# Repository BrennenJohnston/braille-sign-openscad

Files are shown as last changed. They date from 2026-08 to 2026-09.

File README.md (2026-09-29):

# Braille Sign STL Generator (OpenSCAD)





## Overview

A parametric OpenSCAD generator for **two-part tactile signs**: a plate of
raised uppercase letters above a plate of the same wording in braille, following
the 2010 ADA Standards (section 703) recommendations. It is for anyone who needs
a room sign that reads by touch as well as by sight, and for the makers who
print them. The letter plate prints flat and the braille plate prints leaning
back at 75 degrees on break-away fins, because braille printed at 75 to 90
degrees reads faster and more comfortably than flat-printed braille; mounted
touching, the two plates' split borders join into one frame.

One self-contained `.scad` file, MakerWorld-ready, no `include`/`use`.

The picture below shows the default sign the way the printer makes it: the
letter plate lies flat with ROOM 101 in raised letters inside a raised border,
and the braille plate leans back on a row of thin support fins that snap off
after printing. This view shows the back of the braille plate, so its dots face
away from you.

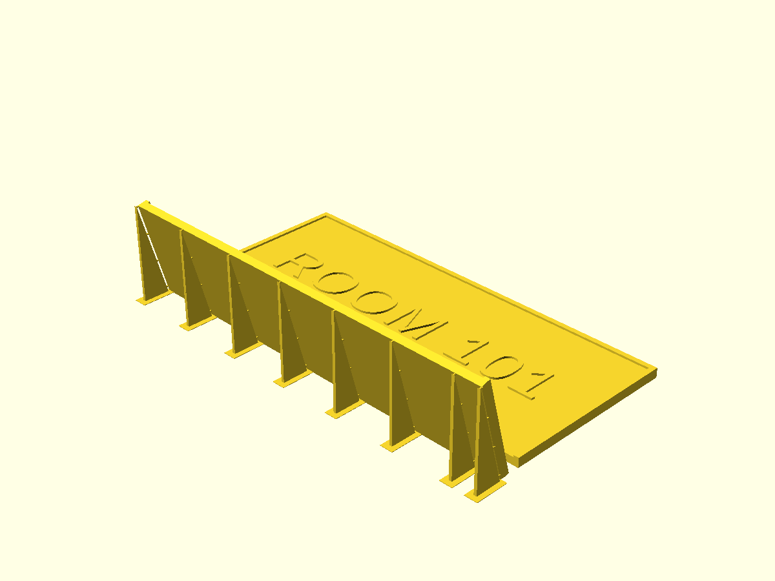
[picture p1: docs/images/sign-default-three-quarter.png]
The default sign as it prints, seen from above and in front. The letter plate lies flat with ROOM 101 in raised capital letters inside a raised border. In front of it the braille plate leans back on a row of thin support fins; this view shows its back and fins, and its braille dots face away.


The two guides to read first: the [quick start](docs/guides/quick-start.md)
(one page, from your wording to a sign on the wall) and the
[Maker Guide](docs/guides/maker-guide.md) (the same path in more depth).

> **ADA note.** The defaults follow the published §703 figures, but this tool
> does **not** guarantee compliance. Real signage has requirements this
> generator does not model — mounting height and location, contrast, glare,
> character width ratios, and the 9.5 mm (3/8 in) minimum braille offset below
> the raised text. Verify against the standard before installing.

## How to obtain the device

### In your browser with the Forge

<https://openscad-assistive-forge.pages.dev/?example=braille-sign>

The Forge is an accessibility-first web customizer that runs entirely in your
browser — no account, no uploads, no OpenSCAD install. It ships this generator
as a built-in tool and translates plain text to Grade 1 or Grade 2 Unicode
braille on your device via liblouis, so you can skip the manual translation
step. It updates its own copy of the generator separately, so its dial names
and defaults can differ from this repository's.

### On your computer with OpenSCAD

Open `Braille_Sign_STL_Generator.scad` in [OpenSCAD](https://openscad.org/)
2021.01 or newer (a development snapshot renders fastest) and show the
Customizer (Window > Customizer; in 2021.01, untick Window > Hide Customizer).
Fill in the four Steps from the top: in **Step 1 - Pick a sample sign or type
your own**, pick a `sample_sign` or type your wording into `text_line_1` to
`text_line_6`; in **Step 2 - Braille, pasted from a translator**, paste Unicode
braille into `braille_line_1` to `braille_line_6`; in **Step 3 - What to
export**, choose `sign_part` and leave `print_orientation` on `Angled`; in
**Step 4 - Size**, leave `auto_fit` on `Yes`. Press F6 to render and export each
plate as an STL. The [quick start](docs/guides/quick-start.md) has every click,
and red words beside the sign in the preview name a problem that the full
guide's [Warnings and notes](docs/guides/full-guide.md#warnings-and-notes)
explains.

`Braille_Sign_STL_Generator.json` sits next to the `.scad`, so OpenSCAD
auto-loads its parameter sets into the Customizer preset dropdown:

- **Default Sign (both plates)** — the first-run defaults.
- **Braille Plate Only (flat)** — one plate, printed dots-up.

Your own saved parameter sets go in the same dropdown via the Customizer's `+`
button. If you keep personal presets (names, contact info in braille), save them
to a file ending in `.local.json` — that pattern is gitignored so they never end
up in a public commit.

### A ready-to-print sample

No OpenSCAD needed: the [`stl/`](stl) folder holds both plates of the Restroom,
Exit, Stairs and Room 101 signs, ready to print. [`stl/README.md`](stl/README.md)
lists each file with its size and print settings.

### MakerWorld

The listing is prepared in
[`docs/MAKERWORLD_LISTING.md`](docs/MAKERWORLD_LISTING.md) and goes live when
the owner publishes it. MakerWorld's Parametric Model Maker takes only the
`.scad` (the `.json` presets do not upload), and it shows no OpenSCAD console,
so [`docs/MAKERWORLD_QUICK_START.md`](docs/MAKERWORLD_QUICK_START.md) describes
each problem by what you can see instead. Both are written to the shared
[Accessible MakerWorld Documentation Standard](https://github.com/BrennenJohnston/accessible-makerworld-doc-standard/blob/main/ACCESSIBLE_MAKERWORLD_DOC_STANDARD.md).

## Build instructions

The [Maker Guide](docs/guides/maker-guide.md), section by section:

1. [Choose a way](docs/guides/maker-guide.md#1-choose-a-way)
2. [Prepare the wording](docs/guides/maker-guide.md#2-prepare-the-wording)
3. [Customize](docs/guides/maker-guide.md#3-customize)
4. [Print](docs/guides/maker-guide.md#4-print)
5. [Mount](docs/guides/maker-guide.md#5-mount)
6. [Check it](docs/guides/maker-guide.md#6-check-it)

What to buy besides filament is in the [bill of materials](docs/guides/bom.md).

## How to use it

The [User Guide](docs/guides/user-guide.md) is for the people who put the sign
up, read it and look after it: who it is for, where ADA 703.4 puts it, how it
reads, care, and its limits.

## How to improve this device

The [full guide](docs/guides/full-guide.md) explains how the sign is built,
every dial, every warning and note, the renamed dials, and the command line.
The [design rationale](docs/guides/design-rationale.md) gives the reason and the
measured number behind each default.

```bash
pip install -r tests/requirements.txt
pytest tests -v
```

- `tests/test_customizer.py`: the dropdowns are well formed, and the presets
  file names only real dials and holds no personal text.
- `tests/test_source_guards.py`: one self-contained file, the pinned font, the
  three export choices, six text and braille line pairs, the tab layout,
  dropdown labels without parentheses, and the braille sliders inside ADA
  Table 703.3.1.
- `tests/test_sample_signs.py`: the sample data is well formed and matches the
  dropdown and the file's tables.
- `tests/test_ada_figures.py`: the capital I height, the width estimate within
  2 %, the braille's 9.5 mm clearance, and the character table against its
  data file.
- `tests/test_render_smoke.py`: each plate renders as one solid, and the
  preview warnings never reach an export.
- `tests/test_release_stls.py`: `stl/README.md` lists every shipped STL, and
  the shipped Restroom letter plate still matches a fresh render.
- `tests/test_full_guide_covers_every_dial.py`: the full guide names every
  dial, quotes every warning and note, and matches the sample data.
- `tests/test_docs_gate.py`: this README and every page under `docs/` meet the
  documentation rules that `scripts/check_docs.py` checks.

The tests marked `requires_openscad` render the sign and need OpenSCAD
installed. `powershell -ExecutionPolicy Bypass -File scripts\scad-check.ps1`
renders the default sign with strict warnings and prints `CHECK PASSED` or
`CHECK FAILED`; [`scripts/README.md`](scripts/README.md) lists every script.
CI (GitHub Actions) runs a lint check, every test that needs no OpenSCAD, and
the render smoke tests on Ubuntu with an OpenSCAD nightly AppImage, on every
pull request.

### Related projects

- [braille-wedge-card-openscad](https://github.com/BrennenJohnston/braille-wedge-card-openscad)
  — directly readable braille cards on the same 75° leaning technique. **This
  generator's commit history lives there**, where it shipped as part of v1.1.0
  before moving to this repo.
- [braille-charm-openscad](https://github.com/BrennenJohnston/braille-charm-openscad)
  — braille charms, pendants, and bracelet clips; split out of the same repo.
- [OpenSCAD Assistive Forge](https://github.com/BrennenJohnston/openscad-assistive-forge)
  — accessibility-first browser customizer that ships all three as built-in
  tools with automatic braille translation
  ([live demo](https://openscad-assistive-forge.pages.dev/)).
- [braille-cylinder-stl-generator-openscad](https://github.com/BrennenJohnston/braille-cylinder-stl-generator-openscad)
  — braille **embossing plates** (emboss + counter pairs) for cylindrical
  objects. The dot geometry here traces back to it.

## Files

Documentation:

| File | What it is |
|---|---|
| `README.md` | this page |
| `docs/guides/quick-start.md` | the whole path on one page |
| `docs/guides/maker-guide.md` | how to make the sign |
| `docs/guides/user-guide.md` | how to place, read and look after it |
| `docs/guides/full-guide.md` | every dial, warning and note |
| `docs/guides/bom.md` | what to buy, and filament per sample |
| `docs/guides/design-rationale.md` | why each default is what it is |
| `docs/MAKERWORLD_LISTING.md` | the MakerWorld listing, ready to paste |
| `docs/MAKERWORLD_QUICK_START.md` | using the file on MakerWorld |
| `CHANGELOG.md` | what changed in each version |
| `okh.yml` | the Open Know-How manifest |

Design files:

| File | What it is |
|---|---|
| `Braille_Sign_STL_Generator.scad` | the generator: open it in OpenSCAD and use the Customizer |
| `Braille_Sign_STL_Generator.json` | Customizer presets, auto-loaded by OpenSCAD |
| `scripts/sample_signs.json` | the sample signs' wording and braille, from liblouis |
| `scripts/glyph_advances.json` | the letter widths behind the width estimate |

Build files:

| File | What it is |
|---|---|
| `stl/*.stl` | both plates of each sample sign, ready to print |
| `stl/README.md` | each STL with its size and print settings |
| `docs/images/*.png` | the preview pictures the guides show |

## License

**PolyForm Noncommercial 1.0.0** — free for personal, educational, and other
noncommercial use; modification and redistribution allowed under the same
terms; **no commercial use**. See [LICENSE](LICENSE). MakerWorld, Printables
and Thingiverse do not offer PolyForm, so the copies there carry the closest
license they do offer, Creative Commons Attribution-NonCommercial 4.0
(CC BY-NC 4.0), chosen by the owner.

## Attribution

- **Brennen Johnston** — project owner; braille dot system and the leaning /
  break-away fin geometry.
- **Puerta, Crnovrsanin, South, Dunne (CHI 2024)** — the orientation research
  the angled braille plate is built on.
- **masukomi** and **Slant3D** — break-away support fin technique.

The research behind the defaults:

- [Puerta et al., CHI 2024](https://doi.org/10.1145/3613904.3642719), "The
  Effect of Orientation on the Readability and Comfort of 3D-Printed Braille":
  braille printed at 75–90° reads significantly faster and more comfortably than
  flat; 75° also reduces dot overhangs vs. 90°. The angled braille plate exists
  for this reason.
- [masukomi, "Manual Support Fins for 3D Printing"](https://weblog.masukomi.org/2024/03/11/manual-support-fins-for-3d-printing/):
  ~1 mm fin offset, a column of small sprues, side fins so edges don't float,
  0.3–0.4 mm contact — the fin/bridge defaults follow this.
- [2010 ADA Standards](https://archive.ada.gov/), section 703: character
  height, raise height, and dot dimension envelope behind the defaults.
- [BANA size and spacing](https://brailleauthority.org/size-and-spacing-braille-characters):
  cell geometry and clear-space guidance behind the spacing defaults.

The documentation and repository structure follow the OpenAT Template created by
Makers Making Change / Neil Squire Society, used under a CC BY-SA 4.0 license:
[github.com/makersmakingchange/OpenAT-Template](https://github.com/makersmakingchange/OpenAT-Template).

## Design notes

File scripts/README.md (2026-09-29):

# Scripts

Helper scripts for this repository. Run each one from the repository root.

| Script | What it does | How to run it |
|---|---|---|
| `scad-check.ps1` | Renders the generator with strict warnings and OpenSCAD's own parameter checks into `build/check.stl`, then prints `CHECK PASSED` or `CHECK FAILED`. | `powershell -ExecutionPolicy Bypass -File scripts\scad-check.ps1` |
| `generate_sample_braille.mjs` | Translates the sample signs to UEB Grade 2 braille with liblouis and writes `scripts/sample_signs.json`. | `node scripts/generate_sample_braille.mjs` |
| `measure_glyph_advances.py` | Measures each character's width in Liberation Sans with OpenSCAD and writes `scripts/glyph_advances.json` and the `GLYPH_METRICS` table. | `python scripts/measure_glyph_advances.py` |
| `build_release_stls.py` | Renders both plates of every sample sign into `stl/`, checks each is watertight, and writes `stl/README.md`. | `python scripts/build_release_stls.py` |
| `render_doc_images.py` | Renders the preview pictures the guides show into `docs/images/` and prints each file's size. | `python scripts/render_doc_images.py` |
| `check_docs.py` | Checks `README.md` and every page under `docs/` against the documentation rules and prints each finding; exits 1 if any fails. | `python scripts/check_docs.py` |

`measure_glyph_advances.py` is run by hand when the font or the width estimate changes; paste the table it prints into the `.scad`.

`build_release_stls.py` is run by hand after any change to the `.scad` that moves the geometry, and the regenerated files are committed; `--out <folder>` renders somewhere else to compare without touching `stl/`.

`render_doc_images.py` is run by hand after a change to the `.scad` that changes what the pictures show; `--only <name>` renders one picture. Look at each picture, and check its alt text in the guide still matches, before committing it.

`check_docs.py` runs in CI through `tests/test_docs_gate.py`; run it yourself after editing the README or any page under `docs/`. Findings in a file a later phase will rewrite print with that phase's tag and do not fail it.

`generate_sample_braille.mjs` is run by hand, never in CI. It needs a local clone of the OpenSCAD Assistive Forge with its liblouis package and braille tables installed; the path is set at the top of the script. Braille in this repository always comes from this script, never typed by hand, and `tests/test_sample_signs.py` checks the file it writes.

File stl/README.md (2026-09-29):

# Sample sign STLs

Ready-to-print plates for the built-in sample signs, rendered from `Braille_Sign_STL_Generator.scad` at its defaults by `scripts/build_release_stls.py`. Each sign is two plates: print both and mount the letter plate above the braille plate.

- Letter plate: print it flat, letters up, at 0.2 mm layers.
- Braille plate: print it as modeled, leaning back on its fins, at 0.1 mm layers with no slicer supports, then snap the fins off.

| File | Sample | Plate | Size (mm) | Print with |
|---|---|---|---|---|
| `restroom-letter-plate.stl` | Restroom | Letter plate | 160.0 × 70.0 × 3.8 | 0.2 mm layers, flat, letters up |
| `restroom-braille-plate.stl` | Restroom | Braille plate | 165.2 × 17.0 × 39.0 | 0.1 mm layers, as modeled, no supports |
| `exit-letter-plate.stl` | Exit | Letter plate | 160.0 × 70.0 × 3.8 | 0.2 mm layers, flat, letters up |
| `exit-braille-plate.stl` | Exit | Braille plate | 165.2 × 17.0 × 39.0 | 0.1 mm layers, as modeled, no supports |
| `stairs-letter-plate.stl` | Stairs | Letter plate | 160.0 × 70.0 × 3.8 | 0.2 mm layers, flat, letters up |
| `stairs-braille-plate.stl` | Stairs | Braille plate | 165.2 × 17.0 × 39.0 | 0.1 mm layers, as modeled, no supports |
| `room-101-letter-plate.stl` | Room 101 | Letter plate | 160.0 × 70.0 × 3.8 | 0.2 mm layers, flat, letters up |
| `room-101-braille-plate.stl` | Room 101 | Braille plate | 165.2 × 17.0 × 39.0 | 0.1 mm layers, as modeled, no supports |

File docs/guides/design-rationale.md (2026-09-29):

# Design rationale

Every default in the generator has a reason. This page gives each one in the
same shape: the decision, the number, the evidence, and what you may change.
The numbers were measured on the files in this repository, and each one names
where it came from.

> **ADA note.** The defaults follow the published §703 figures, but this tool
> does **not** guarantee compliance. Real signage has requirements this
> generator does not model — mounting height and location, contrast, glare,
> character width ratios, and the 9.5 mm (3/8 in) minimum braille offset below
> the raised text. Verify against the standard before installing.

## Two plates, and the braille plate leans back 75°

**The decision.** The sign is two plates. The letter plate prints flat,
letters up. The braille plate prints leaning back on break-away fins:
`print_orientation` is `Angled` and `face_angle_deg` is 75.

**The number.** 75 degrees from the bed. The leaning plate is sunk 0.6 mm into
the bed and cut flat there, so its bottom edge has a real first-layer strip
instead of a knife edge. A fin stands at each end and every 25 mm between
(`fin_interval_mm`): eight fins on the default 160 mm sign. All of these are
in `Braille_Sign_STL_Generator.scad`.

**The evidence.** The Accessible MakerWorld Documentation Standard, section 2,
copied here as it stands:

> **Puerta, Crnovrsanin, South, Dunne — "The Effect of Orientation on the
> Readability and Comfort of 3D-Printed Braille," CHI 2024.** DOI
> [10.1145/3613904.3642719](https://doi.org/10.1145/3613904.3642719)
>
> Why it matters: braille printed on a face angled **75°–90°** from the print
> bed was read significantly faster and more comfortably than flat-printed
> braille, because near-vertical printing moves the layer seams off the surface
> the finger reads. **75°** rather than 90° is the working choice here because it
> reduces the overhang under each dot.

That finding is about braille dots, not raised letters. A dot is 1.6 mm
across, so a layer seam over its crown is a large part of it, and a finger
feels it. A raised letter 16 mm tall is coarse enough that seams do not
matter, and printing it flat gives a cleaner top than any angle would. One
plate would force both kinds of text into one orientation, so the sign is two
plates. At 90 degrees the underside of every dot would be a flat overhang; at
75 degrees the face tilts back and each dot's underside becomes a gentle slope
that prints without supports. The fins, bridges and brims exist to make that
angle printable in one pass.

**What you may change.** `face_angle_deg` runs from 60 to 90; 75 to 90 reads
best, and 75 needs no slicer supports. `print_orientation` `Flat` prints the
braille plate dots up, which puts the layer seams across the dots. The fin,
bridge and brim dials change how the fins hold and how easily they snap off.

## The letter dimensions

**The decision.** `letter_height_mm` is the printed height of the capital I,
16 mm by default. The letters rise 0.8 mm (`letter_raise_mm`), the lines sit
135 % of the letter height apart (`letter_line_spacing_pct`), the spacing
factor is 1.1 (`letter_spacing_factor`), `force_uppercase` is `Yes`, and the
font is Liberation Sans, a sans serif.

**The number.** Liberation Sans draws its capital I at 0.9555 of the font
size: 15.288 mm at size 16, measured before this dial changed meaning. The file
divides `letter_height_mm` by 0.9555 before it sets the size, so the dial at
16 prints an I 16.000 mm tall, at 12 prints 12.000 mm and at 50 prints
49.999 mm. At 16 the O is 99.2 % as wide as the I is tall, the I's stroke is
13.6 % of its height, and two I's sit 4.939 mm apart. Auto-fit's width
estimate came out 0.45 % and 1.16 % wider than the printed letters on its two
test lines, never narrower. All measured on meshes rendered from the file
(`tests/test_ada_figures.py` checks the I and the estimate).

**The evidence.** The standard's section 2, copied as it stands:

> **2010 ADA Standards for Accessible Design, §703.**
> <https://archive.ada.gov/>
>
> Why it matters: §703.3 fixes the braille dot envelope (base 1.5–1.6 mm, height
> 0.6–0.9 mm, domed not pointed); §703.2 fixes raised-character height (minimum
> 15.9 mm / 5/8 in) and relief (minimum 0.8 mm / 1/32 in). Cited as a dimensional
> envelope, **never as a compliance claim** — see §5.

The block's "§5" is the documentation standard's own section on compliance
language. 5/8 in is 15.875 mm; the 2010 Standards print it as "5/8 inch
(16 mm)", and 16 mm is the figure this generator uses. The rest of 703.2, from the Standards'
own text: characters uppercase (703.2.2) and sans serif (703.2.3); the O's
width 55 to 110 % of the I's height (703.2.4); height 16 mm (5/8 in) minimum
and 51 mm (2 in) maximum on the uppercase I, or 13 mm (1/2 in) where separate
raised and visual characters carry the same information (703.2.5); the I's
stroke at most 15 % of its height (703.2.6); 3.2 mm (1/8 in) minimum and four
times the stroke maximum between letters with square sides (703.2.7); lines
135 to 170 % of the letter height apart (703.2.8); relief 0.8 mm (1/32 in)
minimum (703.2.1).

The dial means the printed height because 703.2.5 measures the printed capital
I. When the dial set the font size instead, 16 printed an I 15.288 mm tall,
under the figure, while every document said 16 mm.

**What you may change.** `letter_height_mm` runs from 12 to 50 mm; under 16
the preview shows LETTERS UNDER 16 MM and the console prints a note, but the
sign still renders, because a smaller sign has uses outside the ADA Standards.
`letter_raise_mm` and `letter_line_spacing_pct` stay wide too, and print a
console note outside the ADA figures; `letter_spacing_factor` has no check.
The font is fixed.

## The dot geometry and the 6.5 mm cell pitch

**The decision.** The default Rounded dot is a base 1.6 mm across narrowing to
a 1.4 mm dome, 0.35 mm of base plus 0.35 mm of dome: 0.7 mm tall. Cells are
6.5 mm apart (`braille_cell_spacing_mm`), dots in a cell 2.5 mm
(`braille_dot_spacing_mm`), braille lines 10.0 mm (`braille_line_spacing_mm`).

**The number.** Measured on the plate, a dot stands 0.676 mm proud of the face
on a base ring 1.589 mm across: the 0.7 mm dot sinks 0.02 mm into the face to
fuse with it. At the 6.5 mm pitch, the default ten-cell braille line is
57.4 mm wide.

**The evidence.** ADA Table 703.3.1, from the Standards' own text: dot base
diameter 1.5 to 1.6 mm (0.059 to 0.063 in); dot height 0.6 to 0.9 mm (0.025 to
0.037 in); dots in a cell 2.3 to 2.5 mm (0.090 to 0.100 in) apart; matching
dots in neighboring cells 6.1 to 7.6 mm (0.241 to 0.300 in); a cell and the
cell directly below 10 to 10.2 mm (0.395 to 0.400 in), all center to center;
the dots domed or rounded. And from the standard's section 2, as they stand:

> **ISO 17049:2013, *Accessible design — Application of braille on signage,
> equipment and appliances*.**
> <https://www.iso.org/standard/58090.html>
>
> Why it matters: the international dot geometry range. Where ADA and ISO 17049
> overlap — dot base **1.5–1.6 mm**, dot height **0.6–0.7 mm**, cell pitch
> **6.1–6.8 mm**, line pitch **10.0–10.2 mm** — is the safest target for a model
> that may be read by someone trained on either standard.

> **BANA, *Size and Spacing of Braille Characters*.**
> <https://brailleauthority.org/size-and-spacing-braille-characters>
>
> Why it matters: the source for cell spacing, line spacing, and within-cell dot
> spacing. Dots that are geometrically legal but spaced wrong are unreadable.

The default dot sits inside the overlap: base 1.6 mm, height 0.7 mm, pitch
6.5 mm, line pitch 10.0 mm. The pitch was 7.0 mm, inside ADA but outside the
overlap, and the owner's braille rulebook says 6.5, so the default moved.

The base under the dome is there because a dome alone, kept within a 1.6 mm
base, can be at most 0.8 mm tall: a half sphere is as tall as it gets. The
base lets the dot reach the upper part of the height range at the full base
width, and on the leaning plate it turns the dot's underside into a slope
that prints.

**What you may change.** Every braille slider spans Table 703.3.1 and no
further, and a check in the file stops the render if a preset or a
command-line value goes outside it. `dot_shape` `Cone` gives a pointed dot
with a flat top for printers that print Rounded badly; it is not the domed
shape ADA asks for.

## The 9.5 mm braille clearance

**The decision.** Auto-fit keeps the braille `braille_clearance_mm` (9.5 mm)
inside the border rails; the letters keep 4 mm.

**The number.** On a six-line sign, the braille sits 9.505 mm from the bottom
rail, measured where each dot meets the face (`tests/test_ada_figures.py`
checks it). Before the dial existed it sat 4.005 mm away.

**The evidence.** ADA 703.3.2, from the Standards' own text: "Braille shall be
separated 3/8 inch (9.5 mm) minimum from any other tactile characters and 3/8
inch (9.5 mm) minimum from raised borders and decorative elements." With the
plates touching on the wall, the braille sits 43.473 mm below the lowest
letter on the default sign and 17.505 mm on the six-line sign, measured in the
files.

**What you may change.** `braille_clearance_mm` runs from 9.5 to 20 mm; a
check stops the render below 9.5. With `auto_fit` off, braille that fits the
plate but not with this space shows BRAILLE TOO CLOSE TO BORDER.

## The split border

**The decision.** The letter plate carries the top rail and both side rails;
the braille plate carries the bottom rail and both side rails.

**The number.** Rails 2 mm wide (`border_width_mm`) and 0.8 mm high
(`border_height_mm`), the same height as the letters' relief.

**The evidence.** Mounted touching, letters above braille, the rails join
into one continuous frame. The frame is a tactile boundary: a hand sweeping
the sign finds its edge and knows where the content starts and stops. Both
plates always share one width, so the side rails line up.

**What you may change.** `add_border` `No` leaves both plates without rails;
`border_width_mm` and `border_height_mm` change their size, and auto-fit
counts the width in its spaces.

## The sample signs

**The decision.** `sample_sign` offers Restroom, Exit, Stairs and Room 101.
Their braille is Unified English Braille (UEB) Grade 2 from liblouis, the
open-source translator the OpenSCAD Assistive Forge also uses, written into
`scripts/sample_signs.json` by `scripts/generate_sample_braille.mjs` and never
typed by hand. The braille is lowercase.

**The number.** 7, 4, 5 and 9 braille cells.

**The evidence.** ADA 703.3 asks for contracted braille, Grade 2, on signs.
ADA 703.3.1 allows the braille capital sign only before the first word of a
sentence, proper nouns and names, single letters, initials and acronyms, and a
room name on a sign is none of those, so the owner chose lowercase braille for
the samples. The raised letters are capitals regardless, as 703.2.2 asks.
Tests keep the file's sample tables and the full guide's sample table the
same as the data file.

**An automatic translator is not a certified transcriber.** The samples'
braille has not been checked by one; for a sign in a public building, have a
transcriber certified in UEB check the braille.

**What you may change.** Leave `sample_sign` on `Type my own` and type your
own wording and braille. To change a sample, change the generator script's
input and run it again; the tests fail until the file's tables match.

## Warnings in the preview only

**The decision.** When the generator finds a problem, it draws red words
beside the sign in the desktop preview (orange for the sample note) and
prints the same problem to the console. The words are drawn with OpenSCAD's
background modifier, so they never reach a render or an STL. The owner chose
this over a red tag printed on the bed and over console messages alone.

**The number.** Each message is a line of text 5 mm tall, lying flat 10 mm
beyond the sign's far edge, one line per problem.

**The evidence.** `tests/test_render_smoke.py` renders a sign with a warning
firing, with the words on and off, and finds the two exports identical in
volume, area and bounds to six decimals. MakerWorld's Parametric Model Maker
shows the rendered model, not OpenSCAD's preview or console, so it shows none
of the words; the MakerWorld quick start describes what each problem looks
like there instead.

**What you may change.** `show_warnings` `No` hides the words; the console
still prints every problem.

## 0.1 mm layers for the braille plate

**The decision.** Print the braille plate at 0.1 mm layers; 0.2 mm is fine for
the letter plate.

**The evidence.** The standard's section 2, copied as it stands:

> **Barros, Correia, Teixeira — "Towards the Effectiveness of 3D Printing on
> Tactile Content Creation," Polymers 2023, 15(9):2180.** DOI
> [10.3390/polym15092180](https://doi.org/10.3390/polym15092180)
>
> Why it matters: measured FDM tactile output on a 0.4 mm nozzle at 0.1 mm
> layers. This is the basis for the 0.1 mm layer-height guidance — dot height is
> capped at 0.9 mm by the braille standards, so layer height is the only lever
> left for how smooth a dot feels.

Printed flat, a 0.7 mm dot is seven layers at 0.1 mm and only three or four at
0.2 mm, and a few layers make a staircase a fingertip notices before the dot.

**What you may change.** Layer height is your slicer's setting, not the
file's.

## Print settings as text

**The decision.** Every print setting is written out in words, in the quick
start's [Printing](quick-start.md#printing) section and the Maker Guide's
[4. Print](maker-guide.md#4-print), never only in a slicer profile or a
picture.

**The evidence.** The standard's section 2, copied as it stands:

> **Ballarin, Stangl, Oswal, Whiting — "A Framework-Informed Analysis of
> Accessibility Barriers in Desktop 3D Printing Software," DIS 2025 Companion,
> pp. 477–482.** DOI
> [10.1145/3715668.3736342](https://doi.org/10.1145/3715668.3736342)
>
> Why it matters: measured with NVDA that Cura, PrusaSlicer, and Bambu Studio
> hide much of their interface from the accessibility APIs screen readers use —
> print settings unreachable, controls unlabelled, print errors unannounced.
> This is why a listing must state print settings **as text** and why a
> ready-sliced print profile is an accessibility feature: it removes a step the
> user may not be able to complete.

**What you may change.** Nothing in the file: the settings are advice for
your slicer.

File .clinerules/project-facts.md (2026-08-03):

# Project Facts — braille-sign-openscad (always active)

Two-part tactile signs: raised uppercase letter plate + braille plate.
Working branch: main.

1. Main model: Braille_Sign_STL_Generator.scad.
2. Named checks: powershell -ExecutionPolicy Bypass -File scripts\scad-check.ps1
   (after every .scad edit) and python -m pytest tests/ -v (before commits).
   CI renders with OpenSCAD 2026.01.03 — same as the local canonical binary.
3. Canonical braille constants (do not change without my approval): dot
   spacing 2.5 / cell 6.5 / line 10.0 mm; dot map [[0,0],[1,0],[2,0],[0,1],
   [1,1],[2,1]] = dots 1–6. Full geometry specs live in
   braille-cylinder-stl-generator\docs\specifications\.
4. Signage follows ADA tactile-sign conventions: raised characters AND braille
   are both accessibility features — never trade one off to fit the other;
   flag conflicts to me instead.

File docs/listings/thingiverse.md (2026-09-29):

# Thingiverse listing — Braille Sign STL Generator

Status: ready to upload once the gallery photos are shot.

Written to the listing template of the shared
[Accessible MakerWorld Documentation Standard](https://github.com/BrennenJohnston/accessible-makerworld-doc-standard/blob/main/ACCESSIBLE_MAKERWORLD_DOC_STANDARD.md).
Thingiverse's upload pages could not be read on 2026-09-28, so each field below
is named by what it holds: check the form's own label at upload.

---

## Upload fields

| Field | Label on the form | Value |
|---|---|---|
| Model title | check at upload | `Braille Sign Generator - Two-Part Tactile Room Signs, ADA 703 Dimensions` |
| Category | check at upload | a signs or accessibility category, whichever the list offers |
| License | check at upload | CC BY-NC 4.0: the owner's pick for every platform, 2026-09-28 (Q-10), closest to the repository's PolyForm Noncommercial 1.0.0 |
| Files | check at upload | `restroom-letter-plate.stl`, `restroom-braille-plate.stl`, `exit-letter-plate.stl`, `exit-braille-plate.stl`, `stairs-letter-plate.stl`, `stairs-braille-plate.stl`, `room-101-letter-plate.stl`, `room-101-braille-plate.stl`, `Braille_Sign_STL_Generator.scad`, `Braille_Sign_STL_Generator.json`, and a link to [the quick start](../guides/quick-start.md) |
| Tags | check at upload | `braille`, `accessibility`, `assistive-technology`, `blindness`, `vision-impairment`, `tactile`, `signage`, `ada`, `room-sign`, `wayfinding`, `parametric`, `openscad` |
| External link 1 | check at upload | <https://github.com/BrennenJohnston/braille-sign-openscad> |
| External link 2 | check at upload | <https://openscad-assistive-forge.pages.dev/?example=braille-sign> |

The Thingiverse Customizer app is untested with this file. The file needs
OpenSCAD's `ord()`, `chr()` and `assert()`; OpenSCAD added `ord()` and
`assert()` in version 2019.05, and the app's page does not state which OpenSCAD
version it runs. This listing makes no promise that the Customizer works, and
the tags leave out `customizable` until the checklist's last item has tried it.

CC BY-NC 4.0 is Creative Commons Attribution-NonCommercial 4.0 International.
The owner chose it on 2026-09-28 for every platform; the repository itself stays
under PolyForm Noncommercial 1.0.0. Pick it deliberately rather than accepting
the form's default, and if the form's Creative Commons list names another
version, pick Attribution-NonCommercial and record the version here. The eight
STLs come from the repository's [`stl/` folder](../../stl/README.md), and the
`.scad` and its `.json` presets from the repository's root. The first external
link is the source repository; the second is the accessible browser version of
the same generator.

## Summary

A two-part tactile room sign, read by touch or by sight: a letter plate with
raised capital letters that prints flat, and a braille plate with the same words
that prints leaning back on break-away fins, the two joining into one framed sign
on the wall. Four signs come ready to print (Restroom, Exit, Stairs and Room 101),
and the OpenSCAD file makes one with your own wording. The dimensions follow the
2010 ADA Standards §703 figures, but the generator does **not** guarantee ADA
compliance: see the ADA note in the description.

## Description

*Paste into Thingiverse's description field (check at upload).*

**What this makes**

A room sign in two parts that people can read by sight or by touch. The
**letter plate** carries the words in raised capital letters (Liberation Sans)
and prints flat, letters up. The **braille plate** carries the same words in
braille and prints leaning back at 75 degrees on break-away support fins,
because braille printed on a steep face reads faster and more comfortably than
flat-printed braille (Puerta, Crnovrsanin, South and Dunne, CHI 2024). The letter
plate carries the top and side rails of a raised border and the braille plate the
bottom and side rails, so the two plates mounted touching read as one framed
sign.

> **ADA note.** The defaults follow the published §703 figures, but this tool
> does **not** guarantee compliance. Real signage has requirements this
> generator does not model — mounting height and location, contrast, glare,
> character width ratios, and the 9.5 mm (3/8 in) minimum braille offset below
> the raised text. Verify against the standard before installing.

With the plates mounted touching, the braille sits about 43 mm below the raised
letters on the default sign, more than the 9.5 mm (3/8 in) that §703.3.2 asks.

**Ready to print: four sample signs**

Each sample is two STL files, rendered from the generator at its defaults:

- `restroom-letter-plate.stl` and `restroom-braille-plate.stl`: RESTROOM
- `exit-letter-plate.stl` and `exit-braille-plate.stl`: EXIT
- `stairs-letter-plate.stl` and `stairs-braille-plate.stl`: STAIRS
- `room-101-letter-plate.stl` and `room-101-braille-plate.stl`: ROOM 101

Each letter plate is 160.0 × 70.0 × 3.8 mm and prints flat, letters up. Each
braille plate stands 165.2 × 17.0 × 39.0 mm on the bed and prints exactly as
modeled, leaning back on its fins. The samples' braille is lowercase Unified
English Braille (UEB) Grade 2 from liblouis, an open-source braille translator.

**An automatic translator is not a certified transcriber.** For a sign in a
public building, have the braille checked by a transcriber certified in UEB
before you print.

**Make your own sign in your browser**

The OpenSCAD Assistive Forge runs this generator in a panel built for screen
readers and keyboards, and translates your wording into braille on your own
device with liblouis:

<https://openscad-assistive-forge.pages.dev/?example=braille-sign>

The Forge keeps its own copy of the generator, so its settings can have older
names than the ones below.

**Make your own sign in desktop OpenSCAD**

With OpenSCAD 2021.01 or newer and `Braille_Sign_STL_Generator.scad`:

1. Open `Braille_Sign_STL_Generator.scad` in OpenSCAD.
2. Show the Customizer panel: Window > Customizer (in OpenSCAD 2021.01, untick
   Window > Hide Customizer).
3. Under **Step 1 - Pick a sample sign or type your own**, pick a sample in
   `sample_sign`, or leave it on `Type my own`.
4. With `Type my own`, type your wording into `text_line_1` to `text_line_6`,
   one line of the sign per dial.
5. Under **Step 2 - Braille, pasted from a translator**, paste each line's
   braille into the matching `braille_line_1` to `braille_line_6`.
6. Under **Step 3 - What to export**, set `sign_part` to `Letter plate`.
7. Under **Step 4 - Size**, leave `auto_fit` on `Yes`: the plates grow to fit
   your wording.
8. Press F6 to render the plate.
9. Export it as an STL with File > Export.
10. Set `sign_part` to `Braille plate`.
11. Repeat steps 8 and 9 for the braille plate.

The braille lines take Unicode braille, dot patterns such as ⠑⠭⠊⠞ (Exit), not
ASCII braille, which looks like ordinary letters. The Branah braille translator
(https://www.branah.com/braille-translator) gives it: choose Grade 2 Braille and
Unicode Braille, and type each line in lowercase. Its own page says its Grade 2
is still a work in progress, so check what it gives you, or use the Forge.

**Print settings**

The two plates want different settings, so print them as two jobs, each exactly
as modeled, with no slicer supports:

| Setting | Letter plate | Braille plate |
|---|---|---|
| On the bed | flat, letters up | leaning back on its fins |
| Layer height | 0.2 mm | 0.1 mm |
| Material | PLA or PETG | PLA or PETG |
| Supports | none | none |
| Brim | not needed | optional; one is modeled under each fin |
| Outer wall speed | normal | 30 to 40 mm/s or slower |

The braille plate gets the fine layers because a braille dot is at most 0.9 mm
(0.037 in) tall, so the layer height decides how smooth each dot feels. After
printing, flex or snip the fins off the back of the braille plate and smooth the
small nubs they leave. For contrast, the ADA Standards ask for raised letters
that contrast with their background: add a filament change on the letter plate
at the first layer above 3 mm, or paint the raised letters.

**Mounting, in three lines**

1. Push the plates together, letters above braille, until the side rails meet
   in one frame.
2. Stick them to the wall with the bottom row of braille at least 1220 mm
   (48 in) above the floor.
3. Keep the baseline of the top line of letters at most 1525 mm (60 in) above
   the floor.

**More help**

The quick start walks through every step:
https://github.com/BrennenJohnston/braille-sign-openscad/blob/main/docs/guides/quick-start.md

**Credits**

- Design and code: Brennen Johnston.
- Orientation research: Puerta, Crnovrsanin, South, Dunne (CHI 2024).
- Break-away support fin technique: masukomi, "Manual Support Fins for 3D
  Printing," and Slant3D.
- Braille dot system and the leaning / fin geometry from the braille wedge card
  generator, this project's parent.
- The samples' braille: liblouis.

## Print settings

Short facts for the platform's print settings fields, if its form has them
(check at upload); the description carries the same as text.

| Setting | Letter plate | Braille plate |
|---|---|---|
| Layer height | 0.2 mm | 0.1 mm |
| Material | PLA or PETG | PLA or PETG |
| Supports | none | none (fins modeled) |
| Brim | not needed | optional (one is modeled per fin) |
| Orientation | as modeled, flat | as modeled, leaning 75° |
| Outer wall speed | normal | 30–40 mm/s |

## Gallery plan

The same seven pictures as the MakerWorld listing, with the same alt texts.

1. **Cover — a mounted sign being read.** Both plates mounted on a door frame or
   wall, letters above braille, with a hand on the braille.
   **Alt text:** A two-part printed sign mounted on a wall, reading "Room 101" in
   raised uppercase letters above a braille line, with a hand reading the braille.

2. **The two plates apart.** Both plates side by side on a desk, showing the split
   border.
   **Alt text:** Two printed plates side by side. The upper plate carries raised
   uppercase letters and border rails along its top and sides; the lower plate
   carries braille and border rails along its bottom and sides.

3. **Braille plate on the bed, fins attached.** Side view showing the 75° lean and
   the row of fins.
   **Alt text:** Side view of the braille plate as it comes off the printer,
   leaning back about 75 degrees with several thin triangular support fins
   standing behind it.

4. **Letter plate printing flat.** Top view on the bed.
   **Alt text:** The letter plate lying flat on the print bed with its raised
   uppercase characters facing up.

5. **Dot close-up.** Macro of a braille cell on the finished plate.
   **Alt text:** Close-up of raised braille dots on the sign plate, each dot a
   smooth dome about 1.6 millimeters wide and 0.7 millimeters tall.

6. **Character height with a scale.** Ruler or calipers against a raised
   character.
   **Alt text:** Calipers measuring a raised character on the letter plate at
   about 16 millimeters tall.

7. **Multi-line sign.** A three- or four-line example, both plates.
   **Alt text:** A two-part printed sign with three lines of raised text above
   three matching lines of braille, the plates grown taller to fit.

The cover must be a photograph of the actual printed object, not a render.

## Pre-publish checklist

- [x] **License pick recorded.** CC BY-NC 4.0, the owner's pick for every
      platform on 2026-09-28 (Q-10). Select it deliberately on the upload form.
- [ ] **ADA note present in the description,** near the top. Keep it.
- [ ] **The eight STLs uploaded,** each named as in
      [`stl/README.md`](../../stl/README.md).
- [ ] **The `.scad` uploaded as a source file,** with
      `Braille_Sign_STL_Generator.json` beside it.
- [ ] **Every image has its alt text:** in the uploader's alt text field if it
      has one (check at upload), otherwise pasted into the description, one line
      per picture.
- [ ] **The cover is a real print photo,** ideally the mounted sign.
- [ ] **The quick start linked** from the description, and the link opens: it
      points at `main`, where `docs/guides/quick-start.md` arrives when the
      round's pull requests are merged.
- [ ] **Try the Customizer app once.** If it renders, add the `customizable` tag;
      if not, say so in the description.

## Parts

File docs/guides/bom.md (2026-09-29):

# Bill of materials

A sign needs filament, something to hold it on the wall, and for contrast a
little paint or a second color of filament. There is nothing to solder and no
screws.

| Item | How many | Kind | Where it goes |
|---|---|---|---|
| Filament | see the table below | PLA or PETG | both plates |
| Double-sided mounting tape or adhesive strips | two strips per plate | removable strips or permanent tape | the back of each plate |
| Paint or a second filament | optional | matte, in a color that contrasts with the plate | the raised letters and the border |
| A 3D printer | 1 | a bed at least 170 mm wide for the default sign | both plates |
| Calipers | optional | with a depth rod for the dots | checking the letters and dots |

The plates have flat backs and no mounting holes, so tape or strips are the
only fixing the generator plans for. Contrast is needed on the letters, not
the braille: light letters on a dark plate or dark on light, with a matte
finish that does not glare. A print in one color has no contrast; the
[quick start](quick-start.md#contrast) says how to add it.

## Filament per sample

The numbers below are upper bounds: the solid volume of each shipped STL in
[the stl folder](../../stl/README.md), measured with trimesh, times 1.27 g per
cubic centimeter for PETG. A print with infill uses less. The braille plate's
grams include its fins, bridges and brims, which print with it and then snap
off.

| Sample | Letter plate | Braille plate |
|---|---|---|
| Restroom | 44.0 g | 27.3 g |
| Exit | 43.5 g | 27.3 g |
| Stairs | 43.7 g | 27.3 g |
| Room 101 | 43.9 g | 27.3 g |

Each whole sign, both plates, takes about 71 g of PETG. The solid volumes
behind these grams: the letter plates 34.64 (Restroom), 34.27 (Exit), 34.41
(Stairs) and 34.53 (Room 101) cubic centimeters, and the braille plates 21.47,
21.46, 21.46 and 21.47. For PLA, multiply the grams by 0.98. A sign of your
own at the default size lands near these numbers; a bigger plate takes more,
in step with its area.

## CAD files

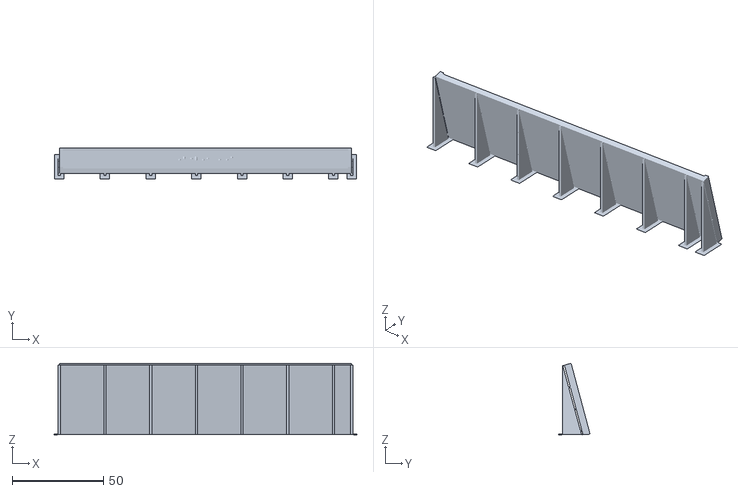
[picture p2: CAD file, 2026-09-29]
stl/stairs-braille-plate.stl
165.2 x 17.0 x 39.0

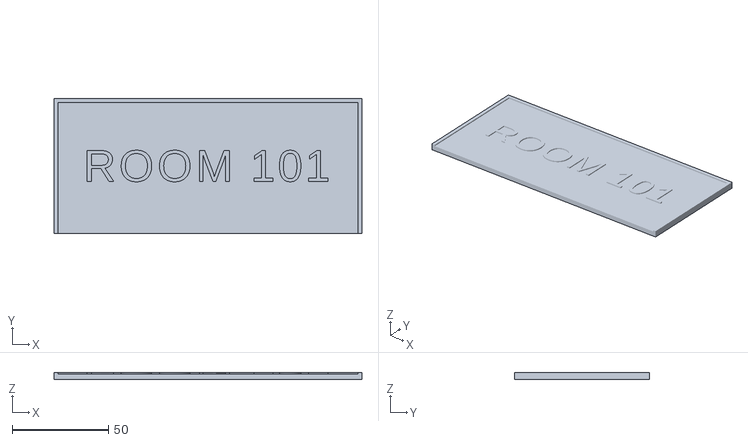
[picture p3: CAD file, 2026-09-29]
stl/room-101-letter-plate.stl
160.0 x 70.0 x 3.80

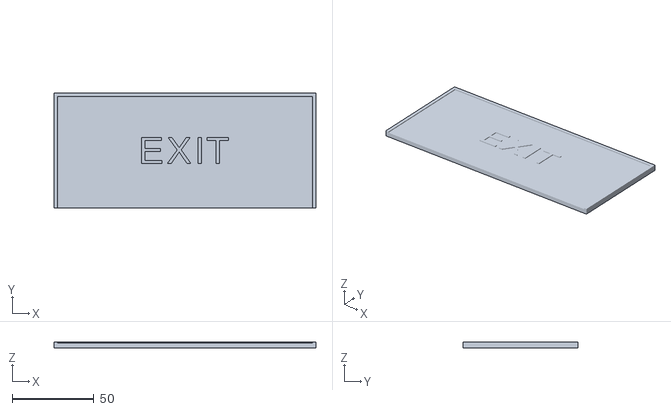
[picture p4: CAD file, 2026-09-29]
stl/exit-letter-plate.stl
160.0 x 70.0 x 3.80

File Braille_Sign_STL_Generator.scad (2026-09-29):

// =============================================================================
// Braille Sign STL Generator (OpenSCAD)
// =============================================================================
// VERSION = 1.0.1
// License: PolyForm Noncommercial 1.0.0
//          https://polyformproject.org/licenses/noncommercial/1.0.0
//
// A two-part tactile sign following the 2010 ADA Standards (section 703)
// recommendations:
//  • LETTER PLATE (top): raised Latin characters (Liberation Sans,
//    sans-serif), uppercase by default, 16 mm character height (5/8 in
//    minimum per 703.2.5), raised 0.8 mm (1/32 in per 703.2.1), 135% line
//    spacing. Prints flat, letters up.
//  • BRAILLE PLATE (bottom): the same text in braille (a sample sign's own,
//    or Unicode braille pasted into braille_line_1..braille_line_6). Prints
//    leaning back at face_angle_deg with break-away support fins by default
//    (the wedge-card technique, crispest dots), or Flat.
//
// SPLIT RAISED BORDER: the letter plate carries the top + side border
// segments and the braille plate carries the bottom + side segments, so
// when the finished plates are mounted with the letters above the braille
// they form ONE continuous tactile frame around the whole sign.
//
// IMPORTANT — ADA disclaimer: these defaults follow the published 703
// figures but this tool does NOT guarantee compliance. Real signage has
// requirements this generator does not model (mounting height and
// location, contrast, glare, character width ratios, braille position
// 9.5 mm (3/8 in) minimum below the raised text, and more). Verify
// against the standard before installing.
//
// =============================================================================
// HOW TO USE: the four Steps at the top of the Customizer
// =============================================================================
//  Step 1 - Pick a sample sign or type your own: pick Restroom, Exit,
//     Stairs or Room 101 under sample_sign, or leave it on Type my own and
//     type your wording into text_line_1..text_line_6 (it becomes the raised
//     letters).
//  Step 2 - Braille, pasted from a translator: for your own wording,
//     translate each line (for example at
//     https://www.branah.com/braille-translator, Unicode braille output, not
//     ASCII braille) and paste it into the matching braille_line_N. A sample
//     sign brings its own braille, so skip this Step. An automatic translator
//     is not a certified transcriber: have a sign for a public building
//     checked.
//  Step 3 - What to export: sign_part Both lays the two plates side by side;
//     Letter plate or Braille plate exports one plate at a time.
//     print_orientation Angled (the default) leans the braille plate back
//     with break-away fins for the crispest dots; Flat prints it dots up.
//  Step 4 - Size: leave auto_fit on Yes and the plates grow so every line of
//     letters and braille fits; the size dials are then minimums, and the
//     size is reported in the console.
//  Then render (F6) and export (File > Export > STL). Print as modeled: no
//  slicer supports needed. Every tab after Step 4 starts with "Advanced".
//
// Lineage: the braille dot system is adapted from the Braille Wedge Card STL
// Generator by Brennen Johnston
// (https://github.com/BrennenJohnston/braille-wedge-card-openscad); the dot
// geometry traces back to the Braille Cylinder STL Generator
// (https://github.com/BrennenJohnston/braille-cylinder-stl-generator-openscad).
// This generator lived in the wedge card repo through v1.1.0 and now has its
// own home at
// https://github.com/BrennenJohnston/braille-sign-openscad
// =============================================================================

/* [Step 1 - Pick a sample sign or type your own] */
// Pick a ready-made sign, or Type my own to use your wording below. A sample ignores the text and braille lines.
sample_sign = "Type my own"; // [Type my own, Restroom, Exit, Stairs, Room 101]
// Line 1 of your wording, as raised letters. Used when sample_sign is Type my own.
text_line_1 = "Room 101";
// Line 2 of your wording. Leave it empty if the sign has fewer lines.
text_line_2 = "";
// Line 3 of your wording. Leave it empty if the sign has fewer lines.
text_line_3 = "";
// Line 4 of your wording. Leave it empty if the sign has fewer lines.
text_line_4 = "";
// Line 5 of your wording. Leave it empty if the sign has fewer lines.
text_line_5 = "";
// Line 6 of your wording. Leave it empty if the sign has fewer lines.
text_line_6 = "";

/* [Step 2 - Braille, pasted from a translator] */
// Braille for text line 1, pasted from a translator as Unicode braille dots, not ASCII letters.
braille_line_1 = "⠠⠗⠕⠕⠍⠀⠼⠁⠚⠁";
// Braille for text line 2. Leave it empty when text line 2 is empty.
braille_line_2 = "";
// Braille for text line 3. Leave it empty when text line 3 is empty.
braille_line_3 = "";
// Braille for text line 4. Leave it empty when text line 4 is empty.
braille_line_4 = "";
// Braille for text line 5. Leave it empty when text line 5 is empty.
braille_line_5 = "";
// Braille for text line 6. Leave it empty when text line 6 is empty.
braille_line_6 = "";

/* [Step 3 - What to export] */
// Which plate to export. Both lays the two plates side by side on the bed.
sign_part = "Both";           // [Both, Letter plate, Braille plate]
// Lean the braille plate back for the crispest dots (Angled) or print it flat (Flat). The letter plate always prints flat.
print_orientation = "Angled"; // [Angled, Flat]

/* [Step 4 - Size] */
// Grow the plates so every line fits (Yes), or keep the exact sizes below (No).
auto_fit = "Yes";             // [Yes, No]
// Width of both plates (mm). When auto_fit is Yes, this is the minimum.
sign_width_mm = 160;          // [60:1:300]
// Height of the letter plate (mm). When auto_fit is Yes, this is the minimum.
letter_plate_height_mm = 70;  // [30:1:200]
// Height of the braille plate (mm). When auto_fit is Yes, this is the minimum.
braille_plate_height_mm = 40; // [25:1:150]

/* [Advanced - Plates and border] */
// Thickness of both plates, not counting the raised letters, dots or border (mm).
plate_thickness_mm = 3;       // [2:0.5:8]
// Space between the two plates on the print bed when sign_part is Both (mm).
plate_gap_mm = 8;             // [2:1:30]
// Add the raised frame: top and sides on the letter plate, bottom and sides on the braille plate.
add_border = "Yes";           // [Yes, No]
// Width of the raised border rails (mm).
border_width_mm = 2;          // [0.5:0.5:6]
// How far the border rises above the plate face (mm).
border_height_mm = 0.8;       // [0.2:0.1:2]

/* [Advanced - Raised letters, ADA 703.2] */
// Turn a to z into capital letters, as ADA 703.2.2 asks. Accented letters stay as typed.
force_uppercase = "Yes";      // [Yes, No]
// Height of the raised capital letters (mm). ADA 703.2.5 asks 16 mm (5/8 in) or more.
letter_height_mm = 16;        // [12:0.5:50]
// How far the letters rise off the plate (mm). ADA 703.2.1 asks 0.8 mm (1/32 in) or more.
letter_raise_mm = 0.8;        // [0.4:0.05:2]
// Baseline-to-baseline spacing of the letter lines, as a percent of the letter height (percent). ADA 703.2.8 asks 135 to 170.
letter_line_spacing_pct = 135; // [100:5:200]
// Spreads or tightens the letters. 1 is the font's own spacing; 1.1 adds a little air.
letter_spacing_factor = 1.1;  // [0.8:0.05:2]

/* [Advanced - Braille spacing, ADA 703.3] */
// Center-to-center distance between braille cells (mm). ADA 703.3.1 asks 6.1 to 7.6; 6.5 is inside ISO 17049 too.
braille_cell_spacing_mm = 6.5; // [6.1:0.1:7.6]
// Center-to-center distance between braille lines (mm). ADA 703.3.1 asks 10.0 to 10.2.
braille_line_spacing_mm = 10.0; // [10.0:0.1:10.2]
// Center-to-center distance between the dots of one cell (mm). ADA 703.3.1 asks 2.3 to 2.5.
braille_dot_spacing_mm = 2.5; // [2.3:0.1:2.5]
// Clear space between the braille and the border rail or plate edge (mm). ADA 703.3.2 asks 9.5 mm (3/8 in) or more.
braille_clearance_mm = 9.5;   // [9.5:0.5:20]
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

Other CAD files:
stl/stairs-letter-plate.stl
stl/room-101-braille-plate.stl
stl/restroom-letter-plate.stl
stl/exit-braille-plate.stl
stl/restroom-braille-plate.stl

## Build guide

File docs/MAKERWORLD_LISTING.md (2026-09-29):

# MakerWorld Listing — Braille Sign STL Generator

Status: ready to upload once the gallery photos are shot.

Written to the shared
[Accessible MakerWorld Documentation Standard](https://github.com/BrennenJohnston/accessible-makerworld-doc-standard/blob/main/ACCESSIBLE_MAKERWORLD_DOC_STANDARD.md).

---

## Upload fields

| Field | Value |
|---|---|
| Model title | `Braille Sign Generator - Two-Part Tactile Room Signs, ADA 703 Dimensions (Parametric)` |
| Designer | Brennen Johnston |
| Category | Education > Other Education Models |
| License | CC BY-NC 4.0 (the repository is PolyForm Noncommercial 1.0.0; MakerWorld does not offer it; the owner's pick, 2026-09-28, Q-10) |
| Upload file | `Braille_Sign_STL_Generator.scad` — this one file only |
| Tags | `braille`, `accessibility`, `assistive-technology`, `blindness`, `vision-impairment`, `tactile`, `signage`, `ada`, `room-sign`, `wayfinding`, `customizable`, `parametric`, `openscad` |
| External link 1 | <https://openscad-assistive-forge.pages.dev/?example=braille-sign> |
| External link 2 | <https://github.com/BrennenJohnston/braille-sign-openscad> |

MakerWorld's license list does not offer PolyForm Noncommercial 1.0.0, the
repository's license, so the owner chose CC BY-NC 4.0 (Creative Commons
Attribution-NonCommercial 4.0 International) on 2026-09-28. Pick it deliberately
at upload time rather than accepting the form's default. The first external link
is the accessible browser version of the same generator; the second is the source
repository.

## Summary

A parametric generator for two-part tactile room signs, read by touch or by
sight, following the 2010 ADA Standards §703 dimensional figures: a letter plate
with raised uppercase characters that prints flat, and a braille plate carrying
the same wording that prints leaning back at 75° for the crispest dots. Pick one
of four sample signs, or type your own wording and paste pre-translated braille,
and both plates size themselves to fit. Mounted touching, letters above braille,
their split raised border joins into one continuous tactile frame.

This tool does **not** guarantee ADA compliance — see the note in the
description.

## Description

*Paste into MakerWorld's description body.*

**What this makes**

Two plates that together form one sign.

The **letter plate** carries raised uppercase characters in Liberation Sans. It
prints flat, letters up, and it carries the top and side rails of the sign's
raised border.

The **braille plate** carries the same wording in braille. It prints leaning back
75 degrees on modeled break-away support fins, and it carries the bottom and
side rails of the border.

Mounted touching, letters above braille, the two sets of border rails join into
one continuous frame — which is both how the sign should look and a tactile
boundary a hand can find before it starts reading.

At the shipped defaults the sign is 160 millimeters wide with a 70 millimeter
letter plate and a 40 millimeter braille plate, both 3 millimeters thick.
Auto-fit is on by default, so those become minimums: the plates grow to fit
whatever wording you enter, up to six lines.

> **ADA note.** The defaults follow the published §703 figures, but this tool
> does **not** guarantee compliance. Real signage has requirements this
> generator does not model — mounting height and location, contrast, glare,
> character width ratios, and the 9.5 mm (3/8 in) minimum braille offset below
> the raised text. Verify against the standard before installing.

With the plates mounted touching, the braille sits about 43 millimeters below the
raised letters on the default sign, more than the 9.5 millimeters (3/8 inch) that
§703.3.2 asks.

**An automatic translator is not a certified transcriber.** For a sign going into
a public building, have the braille checked by a transcriber certified in Unified
English Braille (UEB) first.

**What dimensions the defaults follow**

| Default | §703 figure |
|---|---|
| Character height 16.0 mm, on the capital I | §703.2.5, 16 mm (5/8 in) minimum |
| Character relief 0.8 mm | §703.2.1, 0.8 mm (1/32 in) minimum |
| Line spacing 135% of character height | §703.2.8, 135 to 170% |
| Uppercase characters | §703.2.2 |
| Liberation Sans, sans-serif | §703.2.3 |
| Braille dot 1.6 mm base, 0.7 mm tall, domed | §703.3.1, and the ADA / ISO 17049 overlap |
| Cell spacing 6.5 mm, line spacing 10.0 mm, dot spacing 2.5 mm | §703.3.1, and BANA *Size and Spacing of Braille Characters* |
| Braille 9.5 mm from the border | §703.3.2 |

Below 16 millimeters, desktop OpenSCAD flags the letters in its preview and its
console; MakerWorld shows neither, so keep `letter_height_mm` at 16 or more. The
slider goes down to 12 because a smaller sign has uses outside the ADA Standards,
but below 16 the sign no longer matches the published figure and should not be
described as following it.

**What you need to supply**

Your wording as plain text, and the same wording as pre-translated Unicode
braille, because MakerWorld's customizer cannot translate. A sample sign needs
neither: it brings its own.

Translate at the Branah braille translator
(https://www.branah.com/braille-translator): choose **Grade 2 Braille**
(contracted braille, which §703.3 asks for on signs) and **Unicode Braille**
output, which looks like dot patterns such as ⠑⠭⠊⠞ (Exit), rather than
ASCII or BRF braille, which looks like ordinary letters. Branah's own page says
its Grade 2 is still a work in progress, so check what it gives you. Type each
line in lowercase, keeping a capital only at the start of a sentence and for
names, single letters, initials and acronyms. Translate each line separately so
the braille lines match the text lines.

If you would rather skip the translator, the accessible browser version linked
above translates for you on your own device, with UEB Grade 2 as its default.

**Using the customizer**

1. Under **Step 1 - Pick a sample sign or type your own**, pick a sample sign in
   `sample_sign`, or leave it on `Type my own`. A sample brings its own wording
   and braille: skip to step 4.
2. With `Type my own`, type your wording into `text_line_1` through
   `text_line_6`, one line of the sign per dial.
3. Under **Step 2 - Braille, pasted from a translator**, paste the matching
   Unicode braille into `braille_line_1` through `braille_line_6`. The dials
   pair up: `text_line_2` and `braille_line_2` are the same line of the sign in
   two scripts.
4. Under **Step 3 - What to export**, set `sign_part` to `Letter plate`: the two
   plates need different layer heights, so you export them one at a time. Leave
   `print_orientation` on `Angled`; it affects the braille plate only.
5. Under **Step 4 - Size**, leave `auto_fit` on `Yes`. The plates grow to fit
   both scripts and the size sliders become minimums.
6. Generate the model.
7. Download the STL: this is the letter plate.
8. Set `sign_part` to `Braille plate`.
9. Generate the model again.
10. Download the STL: this is the braille plate.

**Important: MakerWorld does not show this model's warnings.** Desktop OpenSCAD
shows each problem as red words beside the sign in its preview and as a line in
its console; MakerWorld's customizer shows neither. Leaving `auto_fit` on `Yes`
prevents every size problem it would warn about. Two to watch for by eye: a
braille line with blank cells or no dots at all means that line is not Unicode
braille, and a sign that shows a sample's wording instead of yours means
`sample_sign` is not on `Type my own`. The quick start guide linked below lists
every symptom.

**Print settings**

The two plates want different settings, so print them as two jobs.

*Letter plate:* flat, letters up. 0.2 millimeter layers are fine — the characters
rise 0.8 millimeters and stand 16 millimeters tall, coarse features that print
cleanly at ordinary resolution. No supports.

*Braille plate:* exactly as modeled, leaning back 75 degrees. 0.1 millimeter
layers. Braille standards cap dot height at 0.9 millimeters, so layer height is
essentially the only lever on how smooth a dot feels. No slicer supports — the
fins are already modeled with a brim underneath. Slow the outer wall to 30–40
millimeters per second; a thin leaning plate rings badly at speed, and input
shaping helps a lot. After printing, flex the fins off the back and deburr the
small nubs the bridges leave.

If the fins fall over or the bridges break mid-print, raise `bridge_contact_mm`
toward 0.4 millimeters or add more `bridge_count`. If the fins will not snap off
cleanly, lower `bridge_contact_mm` toward 0.2 millimeters.

PLA and PETG both work.

**Contrast.** ADA signage requires characters that contrast with their
background, and a single-color print does not. If your printer can change
filament mid-print, the raised characters and the border are the parts to change
color. Otherwise plan to paint them.

**Why the sign is two plates**

Braille printed on a face angled 75–90 degrees from the print bed reads
significantly faster and more comfortably than flat-printed braille, because
near-vertical printing moves the layer seams off the surface your finger reads.
That result is from Puerta, Crnovrsanin, South and Dunne, "The Effect of
Orientation on the Readability and Comfort of 3D-Printed Braille," CHI 2024
(https://doi.org/10.1145/3613904.3642719).

That finding applies to braille dots and not to raised letters. A braille dot is
1.6 millimeters wide, so a layer seam across its crown is a large fraction of the
feature and a reading finger feels it. A 16 millimeter raised character is coarse
enough that seams do not matter, and printing it flat gives a cleaner top face
than any angle would.

One plate would force both scripts into the same orientation. Two plates let each
script print the way it wants to. That is the whole reason for the design.

Seventy-five degrees rather than ninety, because on a near-vertical face the dots
stick sideways out of a wall and the underside of every dot is an overhang. At 90
degrees that overhang is nearly horizontal; at 75 the face tilts back 15 degrees
and the dot undersides become gentle cones that print support-free.

**An accessible alternative**

This generator also runs as a built-in tool in **OpenSCAD Assistive Forge**, an
accessibility-first browser customizer:
https://openscad-assistive-forge.pages.dev/?example=braille-sign

It translates plain English to braille on your device with liblouis (UEB Grade 2
by default, which is the signage convention), is built for screen readers and
keyboard navigation, saves presets, works offline once installed, and names your
downloads after their content. Use it if the customizer here is difficult with
your screen reader. The Forge renders on your own device; MakerWorld renders on
its servers.

**Quick start guide**

Step-by-step help, and what each problem looks like on MakerWorld:
https://github.com/BrennenJohnston/braille-sign-openscad/blob/main/docs/MAKERWORLD_QUICK_START.md

**Credits**

- Design and code: Brennen Johnston.
- Orientation research: Puerta, Crnovrsanin, South, Dunne (CHI 2024).
- Break-away support fin technique: masukomi, "Manual Support Fins for 3D
  Printing," and Slant3D.
- Braille dot system and the leaning / fin geometry from the braille wedge card
  generator, this project's parent.

Sibling generators using the same technique: a braille card generator for longer
text, and a braille charm, pendant and bracelet-clip generator.

## Print profile notes

There is no `.3mf` to attach — this is a parametric model and the geometry depends
on the user's wording. The settings are stated as text in the description.

If print profiles are added later there should be **two**, one per plate, because
they differ in layer height. Each needs its own photograph of the actual printed
result.

| Setting | Letter plate | Braille plate |
|---|---|---|
| Layer height | 0.2 mm | 0.1 mm |
| Material | PLA Basic or PETG | PLA Basic or PETG |
| Supports | none | none (fins modeled) |
| Brim | not needed | optional (one is modeled per fin) |
| Orientation | as modeled, flat | as modeled, leaning 75° |
| Outer wall speed | normal | 30–40 mm/s |

## Gallery plan

1. **Cover — a mounted sign being read.** Both plates mounted on a door frame or
   wall, letters above braille, with a hand on the braille.
   **Alt text:** A two-part printed sign mounted on a wall, reading "Room 101" in
   raised uppercase letters above a braille line, with a hand reading the braille.

2. **The two plates apart.** Both plates side by side on a desk, showing the split
   border.
   **Alt text:** Two printed plates side by side. The upper plate carries raised
   uppercase letters and border rails along its top and sides; the lower plate
   carries braille and border rails along its bottom and sides.

3. **Braille plate on the bed, fins attached.** Side view showing the 75° lean and
   the row of fins.
   **Alt text:** Side view of the braille plate as it comes off the printer,
   leaning back about 75 degrees with several thin triangular support fins
   standing behind it.

4. **Letter plate printing flat.** Top view on the bed.
   **Alt text:** The letter plate lying flat on the print bed with its raised
   uppercase characters facing up.

5. **Dot close-up.** Macro of a braille cell on the finished plate.
   **Alt text:** Close-up of raised braille dots on the sign plate, each dot a
   smooth dome about 1.6 millimeters wide and 0.7 millimeters tall.

6. **Character height with a scale.** Ruler or calipers against a raised
   character.
   **Alt text:** Calipers measuring a raised character on the letter plate at
   about 16 millimeters tall.

7. **Multi-line sign.** A three- or four-line example, both plates.
   **Alt text:** A two-part printed sign with three lines of raised text above
   three matching lines of braille, the plates grown taller to fit.

The cover must be a photograph of the actual printed object, not a render.
MakerWorld requires at least one real print photo per model and per print
profile.

## Pre-publish checklist

- [x] **License pick recorded.** CC BY-NC 4.0, the owner's pick on 2026-09-28
      (Q-10): MakerWorld does not offer the repository's PolyForm Noncommercial
      1.0.0. Select it deliberately on the upload form.
- [ ] **ADA disclaimer present in the description.** Non-negotiable. The note is
      written above — keep it, and keep it near the top rather than buried at the
      end.
- [ ] **Single-file requirement verified.** Run `pytest tests -v` —
      `test_source_guards.py::TestMakerWorldSingleFile` asserts there is no
      `include`/`use` in the `.scad`, and the same file pins the font to
      Liberation Sans.
- [ ] **Customizer dropdown hygiene verified.** Same run: `test_customizer.py`
      checks for `value:Label` option syntax, defaults missing from their own
      option list, and duplicate options.
- [ ] **Font availability confirmed in the Creator Portal.** The `.scad` hardcodes
      Liberation Sans. Render on MakerWorld and confirm the letters appear — a
      missing font renders as nothing, and there is no console to tell you why.
- [ ] **Creator Portal smoke test.** Upload, render `sign_part = Both` at the
      defaults, then render each plate separately and confirm the two exports have
      matching widths. Pick one sample sign in `sample_sign` and confirm its
      braille dots appear.
- [ ] **Warning-blindness acknowledged in the description.** MakerWorld shows
      neither the console nor the desktop preview's red warning words, so the
      description must tell the user to leave `auto_fit` on and what to look for
      on the model. That paragraph is written above — keep it.
- [ ] **Every gallery image has alt text pasted into MakerWorld's field.**
- [ ] **Cover photo is a real printed object,** and ideally a mounted one, since
      mounting is the part the generator cannot do for the user.
- [ ] **Quick start linked from the description** — the description carries the
      GitHub link to [`MAKERWORLD_QUICK_START.md`](MAKERWORLD_QUICK_START.md);
      keep it, or paste the guide's content into the instructions area.

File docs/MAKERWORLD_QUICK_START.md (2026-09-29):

# MakerWorld Quick Start — Braille Sign

This guide takes you from "I need a room sign with braille on it" to two
downloadable, print-ready STLs, using
[`Braille_Sign_STL_Generator.scad`](../Braille_Sign_STL_Generator.scad) on
[MakerWorld](https://makerworld.com/)'s Parametric Model Maker. That one file is
the whole upload.

The generator makes a **two-part sign**: a **letter plate** carrying raised
uppercase characters, and a **braille plate** carrying the same wording in
braille. They are separate plates because they want opposite print orientations —
raised letters print best flat, braille prints best leaning back. Mounted
touching, letters above braille, their split borders form one continuous tactile
frame.

> **ADA note.** The defaults follow the published §703 figures, but this tool
> does **not** guarantee compliance. Real signage has requirements this
> generator does not model — mounting height and location, contrast, glare,
> character width ratios, and the 9.5 mm (3/8 in) minimum braille offset below
> the raised text. Verify against the standard before installing.

---

## 1. What to include

A sign says one thing. The 2010 ADA Standards ask for **uppercase** raised
characters at least **16 mm (5/8 in)** tall, which sets the scale: at the
default `letter_height_mm` of 16 and `letter_line_spacing_pct` of 135, each line
of letters takes 21.6 mm of plate height before margins.

- If your sign is one of the samples, pick it: `sample_sign` offers Restroom,
  Exit, Stairs and Room 101, each with its own wording and braille, so you can
  skip section 2.
- Otherwise `text_line_1` to `text_line_6` hold up to six lines of raised
  letters, and `braille_line_1` to `braille_line_6` hold the matching braille.
  **They pair up**: `text_line_2` and `braille_line_2` are the same line of the
  sign in two scripts.
- Leave `auto_fit` on `Yes` and the plates grow to fit whatever you enter, so
  there is no fixed capacity to plan around. The default `sign_width_mm` of
  160 mm and plate heights of 70 mm (letters) and 40 mm (braille) become minimums.
- Keep it to what a person needs at a doorway: a room number, a room name, a
  direction. `Room 101`. `Exit`. `Staff Only`. Long sentences belong on a
  document, not a sign.
- At the default letter height, a line of raised letters is more than twice as
  wide as its braille (RESTROOM: about 144 mm of letters over 43 mm of braille),
  so the letters are what make a long sign wider.

## 2. Translate your text

Skip this section if you picked a sample sign: it brings its own braille.

MakerWorld's customizer cannot translate English for you. You type your plain
text into `text_line_1` to `text_line_6` for the raised letters, and separately
paste **pre-translated Unicode braille (U+2800–U+28FF)**, the characters that
look like patterns of dots, into `braille_line_1` to `braille_line_6`.

Signs use contracted braille: Grade 2, where common words and letter groups are
shortened, as ADA 703.3 asks. The steps below use [the Branah braille
translator](https://www.branah.com/braille-translator). Its own page says its
Grade 2 is still a work in progress and may shorten a word where it should not,
so check what it gives you, or use the OpenSCAD Assistive Forge (section 8),
which translates with liblouis.

1. Open the Branah braille translator.
2. Choose **Grade 2 Braille**.
3. Choose **Unicode Braille**, not ASCII or BRF braille. Unicode braille looks
   like dot patterns: Room 101 is `⠗⠕⠕⠍⠀⠼⠁⠚⠁`. ASCII braille looks like
   ordinary letters and punctuation and does not work.
4. Type one line of your wording in lowercase. Keep a capital only at the start
   of a sentence and for names, single letters, initials and acronyms: those are
   the only places ADA 703.3.1 allows the braille capital sign.
5. Copy the braille.
6. Paste it into the matching braille line: `braille_line_1` for line 1,
   `braille_line_2` for line 2, and so on.
7. Repeat steps 4 to 6 for each line.

The shipped default is `text_line_1` = `Room 101`, with its braille in
`braille_line_1`. Replace both.

**An automatic translator is not a certified transcriber.** For a sign that will
be installed in a public building, have a transcriber certified in Unified
English Braille (UEB) check the braille before you print a set.

## 3. Using the customizer

The Customizer's first four tabs, **Step 1** to **Step 4**, hold everything a
first sign needs. Every tab after them starts with "Advanced", and every dial
there has a working default.

1. Go to MakerWorld → **Create** → **Parametric Model Maker** and upload
   **only** `Braille_Sign_STL_Generator.scad`.
2. Under **Step 1 - Pick a sample sign or type your own**, pick a sample sign in
   `sample_sign` (`Restroom`, `Exit`, `Stairs` or `Room 101`), or leave it on
   `Type my own`. A sample brings its own wording and braille: go on to step 5.
3. With `Type my own`, type your wording into `text_line_1` to `text_line_6`,
   one line of the sign per dial. Leave unused lines empty.
4. Under **Step 2 - Braille, pasted from a translator**, paste the matching
   Unicode braille into `braille_line_1` to `braille_line_6` (section 2).
5. Under **Step 3 - What to export**, set `sign_part` to `Letter plate`. `Both`
   lays the two plates side by side on the bed, `plate_gap_mm` (8 mm) apart, but
   the plates print best with different settings (section 4), so export them one
   at a time.
6. Leave `print_orientation` on `Angled`. This affects the **braille plate
   only**, which then prints leaning back on break-away fins; the letter plate
   always prints flat.
7. Under **Step 4 - Size**, leave `auto_fit` on `Yes`. The plates then grow to
   fit both scripts, treating `sign_width_mm`, `letter_plate_height_mm` and
   `braille_plate_height_mm` as minimums. Turning it off means you are
   responsible for the sign being big enough.
8. Generate the model.
9. Download the STL: this is the letter plate.
10. Set `sign_part` to `Braille plate`.
11. Generate the model again.
12. Download the STL: this is the braille plate.

You can leave the Advanced tabs alone. What each one holds, with its defaults:

| Tab | What it holds |
|-----|---|
| Advanced - Plates and border | `plate_thickness_mm` (3), `plate_gap_mm` (8), `add_border` (`Yes`), `border_width_mm` (2), `border_height_mm` (0.8) |
| Advanced - Raised letters, ADA 703.2 | `force_uppercase` (`Yes`), `letter_height_mm` (16), `letter_raise_mm` (0.8), `letter_line_spacing_pct` (135), `letter_spacing_factor` (1.1) |
| Advanced - Braille spacing, ADA 703.3 | `braille_cell_spacing_mm` (6.5), `braille_line_spacing_mm` (10.0), `braille_dot_spacing_mm` (2.5), `braille_clearance_mm` (9.5) |
| Advanced - Braille dot shape | `dot_shape` (`Rounded`), then the size of the `Rounded` and the `Cone` dot |
| Advanced - Braille plate lean and support fins | `face_angle_deg` (75), `support_fins` (`Yes`), then the fin, bridge and brim sizes |
| Advanced - Warnings and rendering | `show_warnings` (`Yes`), `render_quality` (`Medium`), `dot_segments` (40) |

The font is fixed at Liberation Sans and is not a parameter. It is a sans-serif
face, which is what §703.2.3 asks for, and it is a font MakerWorld's renderer
reliably has.

## 4. The two-part workflow

The two plates want different print settings, so print them as two jobs.

| | Letter plate | Braille plate |
|--|---|---|
| Orientation | flat, letters up | leaning back 75° |
| Supports | none | none (modeled fins) |
| Layer height | 0.2 mm is fine | 0.1 mm |
| Carries | top and side border rails | bottom and side border rails |

The raised letters stand 16 mm tall and rise 0.8 mm off the plate — coarse
features that print cleanly flat at ordinary layer heights. A braille dot is
0.7 mm tall and 1.6 mm across, which is why the braille plate gets the angled
orientation and the fine layer height.

`sign_part` = `Both` puts both plates on one bed for convenience, but if you
print them together you have to compromise on layer height. Exporting them
separately and slicing each with its own settings gives a better sign.

**Mounting them.** The two plates touch on the wall, letters above braille. The
letter plate carries the top and side rails of the raised border and the braille
plate the bottom and side rails, so when the plates meet, the rails run as one
frame around the sign, square and continuous under a hand.

1. Lay the letter plate above the braille plate, both face up.
2. Push the plates together until their side rails meet in one straight line.
3. Stick adhesive strips or double-sided tape to the back of each plate.
4. Pick the height on the wall: the bottom row of braille at least 1220 mm
   (48 in) above the floor, and the baseline of the top line of letters (the
   line the letters stand on) at most 1525 mm (60 in) above the floor.
5. Press the letter plate onto the wall.
6. Press the braille plate onto the wall right below it, with the side rails
   meeting.

ADA §703.3.2 asks for at least 9.5 mm (3/8 in) between the braille and the
raised letters. With the plates touching, the generator's spacing already gives
more than that: about 43 mm on the default sign.

§703.4 also says which side of the door the sign goes on. The
[User Guide](guides/user-guide.md#where-it-goes) gives those rules in plain words.

## 5. Printing it

**Print each plate exactly as modeled.** Do not rotate them, and do not add
slicer supports.

| Setting | Letter plate | Braille plate |
|---|---|---|
| Layer height | 0.2 mm | 0.1 mm |
| Material | PLA or PETG | PLA or PETG |
| Supports | none | none |
| Brim | not needed | optional (one is modeled under each fin) |
| Outer wall speed | normal | 30–40 mm/s or slower |

Why 0.1 mm on the braille plate: braille standards cap dot height at 0.9 mm, so
the number of layers in a dot — and therefore how smooth it feels — is set almost
entirely by layer height. There is no other lever.

Why to slow the outer wall on the braille plate: it is a thin plate leaning at
75° and it rings badly at speed. Input shaping helps a lot if your printer has
it.

After printing the braille plate: flex or snip the fins off the back, then deburr
the small nubs the bridges leave with a fingernail or fine sandpaper.

**Contrast.** The ADA Standards ask for raised characters that contrast with
their background, and a print in one color has none. If your slicer can pause for a
filament change, add one on the letter plate at the first layer above 3 mm, the
top of the plate at the default `plate_thickness_mm`, so the raised characters
and the border print in the second color. Otherwise, paint the raised characters
in a matte color that contrasts with the plate. The braille does not need to
contrast.

## 6. Why we designed it this way

### The braille plate leans back 75°; the letter plate lies flat

**The decision:** `print_orientation = Angled` at `face_angle_deg = 75` for the
braille plate. The letter plate always prints flat.

**The evidence:**

> **Puerta, Crnovrsanin, South, Dunne — "The Effect of Orientation on the
> Readability and Comfort of 3D-Printed Braille," CHI 2024.** DOI
> [10.1145/3613904.3642719](https://doi.org/10.1145/3613904.3642719)
>
> Why it matters: braille printed on a face angled **75°–90°** from the print
> bed was read significantly faster and more comfortably than flat-printed
> braille, because near-vertical printing moves the layer seams off the surface
> the finger reads. **75°** rather than 90° is the working choice here because it
> reduces the overhang under each dot.

**Why not put both scripts on one plate?** Because the finding above applies to
braille dots and not to raised letters. A braille dot is 1.6 mm wide, so a layer
seam across its crown is a large fraction of the feature and a reading finger
feels it. A 16 mm-tall raised character is coarse enough that seams do not
matter, and printing it flat gives a cleaner top face than any angle would. One
plate would force both scripts into whichever orientation you chose, so the sign
is two plates instead. This is the whole reason for the two-part design.

**Why 75° rather than 90°.** On a near-vertical face the dots stick sideways out
of a wall, so the underside of every dot is an overhang. At 90° that overhang is
nearly horizontal and needs support or prints rough; at 75° the face tilts back
15° and the dot undersides become gentle cone-shaped overhangs that print
support-free. The fins, the bridges, and the brim all exist to make that angle
printable in one pass.

**What you may change:** `face_angle_deg` runs from 60 to 90; 75 to 90 reads
best, and 75 needs no slicer supports. `print_orientation` = `Flat` prints the
braille plate dots up, which puts the layer seams across the dots.

### The letter dimensions come from ADA §703.2

**The decision:** `letter_height_mm` 16 mm, the printed height of the capital I;
`letter_raise_mm` 0.8 mm; `letter_line_spacing_pct` 135; `letter_spacing_factor`
1.1; `force_uppercase` = `Yes`; a sans-serif font.

**The number:** Liberation Sans draws its capital I at 0.9555 of the font size,
so the file divides `letter_height_mm` by 0.9555 before it sets the size: the
dial at 16 prints an I 16.0 mm tall, measured on the mesh. The dial means the
printed height because §703.2.5 measures the printed capital I.

**The evidence:**

> **2010 ADA Standards for Accessible Design, §703.**
> <https://archive.ada.gov/>
>
> Why it matters: §703.3 fixes the braille dot envelope (base 1.5–1.6 mm, height
> 0.6–0.9 mm, domed not pointed); §703.2 fixes raised-character height (minimum
> 15.9 mm / 5/8 in) and relief (minimum 0.8 mm / 1/32 in). Cited as a dimensional
> envelope, **never as a compliance claim** — see §5.

The block's "§5" is the documentation standard's own section on compliance
language, not section 5 of this guide. 5/8 in is 15.875 mm; the 2010 Standards
print it as "5/8 inch (16 mm)", and 16 mm is the figure this generator uses.

The specific figures each default answers:

| Default | §703 figure |
|---|---|
| `letter_height_mm = 16` | §703.2.5, 16 mm (5/8 in) minimum, on the capital I |
| `letter_raise_mm = 0.8` | §703.2.1, 0.8 mm (1/32 in) minimum |
| `letter_line_spacing_pct = 135` | §703.2.8, 135 to 170% of the letter height |
| `letter_spacing_factor = 1.1` | §703.2.7, character spacing |
| `force_uppercase = Yes` | §703.2.2, uppercase characters |
| Liberation Sans | §703.2.3, sans serif |

**What you may change:** below 16 mm, desktop OpenSCAD's preview shows LETTERS
UNDER 16 MM and its console prints a note; MakerWorld shows neither. The slider
allows values down to 12 mm because a smaller sign has uses outside the ADA
Standards, but below 16 mm you are no longer inside the figure the standard
publishes, and the sign should not be described as following it.
`letter_raise_mm` and `letter_line_spacing_pct` also print a console note outside
their ADA figures; `letter_spacing_factor` has no check.

### The braille dot geometry and spacing

**The decision:** the default `Rounded` dot is a 1.6 mm base tapering to a
1.4 mm dome, 0.35 mm of base plus 0.35 mm of dome — **0.7 mm total height on a
1.6 mm base**. Spacing is `braille_cell_spacing_mm` 6.5 mm,
`braille_line_spacing_mm` 10.0 mm, `braille_dot_spacing_mm` 2.5 mm.

**The number:** measured on the plate, a dot stands 0.68 mm proud of the face,
because it sinks 0.02 mm into the plate to fuse with it.

**The evidence:** ADA Table 703.3.1, from the Standards' own text: dot base
diameter 1.5 to 1.6 mm (0.059 to 0.063 in); dot height 0.6 to 0.9 mm (0.025 to
0.037 in); dots in a cell 2.3 to 2.5 mm (0.090 to 0.100 in) apart; matching dots
in neighboring cells 6.1 to 7.6 mm (0.241 to 0.300 in); a cell and the cell
directly below 10 to 10.2 mm (0.395 to 0.400 in), all center to center; the dots
domed or rounded. And from the documentation standard's evidence library:

> **ISO 17049:2013, *Accessible design — Application of braille on signage,
> equipment and appliances*.**
> <https://www.iso.org/standard/58090.html>
>
> Why it matters: the international dot geometry range. Where ADA and ISO 17049
> overlap — dot base **1.5–1.6 mm**, dot height **0.6–0.7 mm**, cell pitch
> **6.1–6.8 mm**, line pitch **10.0–10.2 mm** — is the safest target for a model
> that may be read by someone trained on either standard.

> **BANA, *Size and Spacing of Braille Characters*.**
> <https://brailleauthority.org/size-and-spacing-braille-characters>
>
> Why it matters: the source for cell spacing, line spacing, and within-cell dot
> spacing. Dots that are geometrically legal but spaced wrong are unreadable.

> **Barros, Correia, Teixeira — "Towards the Effectiveness of 3D Printing on
> Tactile Content Creation," Polymers 2023, 15(9):2180.** DOI
> [10.3390/polym15092180](https://doi.org/10.3390/polym15092180)
>
> Why it matters: measured FDM tactile output on a 0.4 mm nozzle at 0.1 mm
> layers. This is the basis for the 0.1 mm layer-height guidance — dot height is
> capped at 0.9 mm by the braille standards, so layer height is the only lever
> left for how smooth a dot feels.

The default dot sits inside the ADA and ISO 17049 overlap: base 1.6 mm, height
0.7 mm, cell pitch 6.5 mm, line pitch 10.0 mm.

**Why a base under the dome.** A pure spherical dome on a 1.6 mm base physically
cannot exceed 0.8 mm tall — a hemisphere is as tall as it gets. The tapered base
section is what lets the dot reach the upper part of the legal height range while
keeping the legal base width, and it is also what turns the dot's underside into a
printable overhang when the plate leans.

**Why the layer height matters more than it looks like it should.** Because the
standards cap the dot at 0.9 mm, the only remaining control over how a dot feels
is how finely it is sliced. Printed flat, a 0.7 mm dot is seven layers at 0.1 mm
and only three or four at 0.2 mm, and a few layers make a staircase the fingertip
notices instead of the dot.

**What you may change:** every braille slider spans Table 703.3.1 and no
further, and a check in the file stops the render if a value goes outside it.
`dot_shape` = `Cone` gives a pointed dot with a flat top for printers that print
`Rounded` badly; it is not the domed shape ADA asks for.

### The 9.5 mm braille clearance

**The decision:** auto-fit keeps the braille `braille_clearance_mm` (9.5 mm)
inside the border rails; the letters keep 4 mm.

**The number:** on a six-line sign, the braille sits 9.505 mm from the bottom
rail, measured where each dot meets the face. With the plates touching on the
wall, the braille sits 43.473 mm below the lowest letter on the default sign.

**The evidence:** ADA 703.3.2, from the Standards' own text: "Braille shall be
separated 3/8 inch (9.5 mm) minimum from any other tactile characters and 3/8
inch (9.5 mm) minimum from raised borders and decorative elements."

**What you may change:** `braille_clearance_mm` runs from 9.5 to 20 mm, and a
check stops the render below 9.5. With `auto_fit` off, braille that fits the
plate but not with this space sets off BRAILLE TOO CLOSE TO BORDER (section 7).

### The border is split between the plates

The letter plate carries the top and side rails; the braille plate carries the
bottom and side rails. Mounted touching, letters above braille, they read as one
continuous frame. Beyond looking right, the frame is a tactile boundary: a hand
sweeping the sign finds the edge and knows where the content starts.
`border_width_mm` defaults to 2 mm and `border_height_mm` to 0.8 mm, matching the
letter relief.

### What this generator does not do

Being explicit about the gaps is part of the design:

- **Mounting height and location (§703.4)** — not modeled. Section 4 gives the
  heights, and the User Guide the side of the door.
- **Contrast and glare (§703.5)** — a single-color print has no contrast.
- **Character width ratios (§703.2.4)** — the font's proportions are the font's.
- **Verified translation** — an automatic translator is not a certified transcriber.

### Why a parametric upload at all

> **Siu, Kim, Miele, Follmer — "shapeCAD: An Accessible 3D Modelling Workflow
> for the Blind and Visually-Impaired Via 2.5D Shape Displays," ASSETS 2019.**
> DOI [10.1145/3308561.3353782](https://doi.org/10.1145/3308561.3353782)
>
> Why it matters: identifies that mainstream CAD is visually dependent enough to
> force blind designers to work through sighted intermediaries, and builds its
> accessible workflow **on OpenSCAD** specifically because the design is text.
> Every model in this family is an OpenSCAD script for this reason.

> **Zhang, Li, Yu, Faruqi, Xie, Kim, Fan, Forbes, Wobbrock, Guo, He —
> "A11yShape: AI-Assisted 3-D Modeling for Blind and Low-Vision Programmers,"
> ASSETS 2025.** DOI
> [10.1145/3663547.3746362](https://doi.org/10.1145/3663547.3746362)
>
> Why it matters: four blind and low-vision programmers independently produced
> 12 models in OpenSCAD — "tasks that were previously impossible without
> assistance from sighted individuals." The finding that makes a parametric
> upload worth the effort: a customizer panel over a script is something a blind
> maker can drive alone, where a mesh editor is not.

The person who most needs a braille sign should be able to make one without
asking a sighted person to drive the software. That is why this is a script with
a parameter panel and not a mesh.

## 7. Troubleshooting

**Read this first.** MakerWorld shows none of this model's warnings. In desktop
OpenSCAD, the generator shows each problem twice: as red words beside the sign
in the preview, and as a line with its numbers in the console under the preview.
The red words are on while `show_warnings`, under **Advanced - Warnings and
rendering**, is `Yes`, its default. MakerWorld's Parametric Model Maker shows the
rendered model only, without the preview words and without a console. So each
entry below starts with what you can see on MakerWorld, then gives the exact
words desktop OpenSCAD shows, then the fix in order of preference. The
[full guide](guides/full-guide.md#warnings-and-notes) explains every warning and
note for desktop OpenSCAD.

In the console texts below, a word in braces, such as `{n}`, stands for the
number or name the console prints.

The best defense: **leave `auto_fit` on `Yes`.** Every "too tall", "too wide"
and "too close" warning below appears only with `auto_fit` off.

### A braille cell renders as a blank patch with no dots

- **On MakerWorld:** no message. The braille line has blank cells where dots
  should be, or no dots at all when the whole line is typed letters. A character
  that is not braille prints no dots, so the plate still renders.
- **In desktop OpenSCAD:** the preview shows `NOT BRAILLE IN LINE {n}`, and the
  console prints
  `WARNING: braille_line_{n} contains non-braille characters. Use Unicode braille (U+2800-U+28FF).`
- **Fix:** you pasted typed letters or ASCII/BRF braille into that braille line.
  Translate it again with **Unicode braille** output (section 2) and paste the
  result. An ordinary space also sets off the warning, though it prints the same
  blank cell: between braille words, use the blank braille cell, U+2800.

### Text or braille overflows the plate

- **On MakerWorld:** no message. Letters or dots run over a border rail or past
  the edge of the plate; a long line of letters can hang off both sides.
- **In desktop OpenSCAD:** the preview shows one of these red words, and the
  console prints the line beside it, with the measured size against the space
  available and the size you would need:
  - `TEXT TOO WIDE`:
    `WARNING: TEXT TOO WIDE: {estimate}/{space} mm (estimated from character advances, so treat it as approximate). Turn on auto_fit, raise sign_width_mm to at least {width}, or shorten the line.`
  - `TEXT TOO TALL`:
    `WARNING: TEXT TOO TALL: {block}/{space} mm. The raised text block is taller than the letter plate's usable height. Turn on auto_fit, raise letter_plate_height_mm to at least {height}, or remove a line.`
  - `BRAILLE TOO WIDE`:
    `WARNING: BRAILLE TOO WIDE: {block}/{space} mm (longest line is {cells} cells). Turn on auto_fit, raise sign_width_mm to at least {width}, or shorten the line.`
  - `BRAILLE TOO TALL`:
    `WARNING: BRAILLE TOO TALL: {block}/{space} mm. The braille block is taller than the braille plate's usable height. Turn on auto_fit, raise braille_plate_height_mm to at least {height}, or remove a line.`
- **Fix, in order of preference:**
  1. Set `auto_fit` to `Yes` — this cannot happen in auto-fit mode.
  2. Raise `sign_width_mm`, `letter_plate_height_mm`, or
     `braille_plate_height_mm`.
  3. Shorten or remove a line.

The text-width check is estimated from character advances rather than measured,
so treat a marginal case as marginal and look at the preview.

### The braille sits too close to the border

- **On MakerWorld:** no message. The braille fits inside the rails but sits
  closer than `braille_clearance_mm` (9.5 mm, 3/8 in) to a rail or to the top
  edge of the braille plate, which is hard to judge by eye.
- **In desktop OpenSCAD:** the preview shows `BRAILLE TOO CLOSE TO BORDER`, and
  the console prints one of these, for the height or for the width:
  - `WARNING: BRAILLE TOO CLOSE TO BORDER: {block}/{space} mm. ADA 703.3.2 asks {clearance} mm of clear space. Turn on auto_fit, raise braille_plate_height_mm to at least {height}, or remove a line.`
  - `WARNING: BRAILLE TOO CLOSE TO BORDER: {block}/{space} mm (longest line is {cells} cells). ADA 703.3.2 asks {clearance} mm of clear space. Turn on auto_fit, raise sign_width_mm to at least {width}, or shorten the line.`
- **Fix, in order of preference:**
  1. Set `auto_fit` to `Yes`.
  2. Raise `braille_plate_height_mm` or `sign_width_mm`, whichever the console
     names.
  3. Shorten or remove a line.

### The letters are shorter than 16 mm

- **On MakerWorld:** nothing — the sign renders fine. This is the problem you
  are most likely to miss on MakerWorld, so check the number directly:
  `letter_height_mm` must be at least **16** for the sign to match the published
  figure. It defaults to 16.
- **In desktop OpenSCAD:** the preview shows `LETTERS UNDER 16 MM`, and the
  console prints
  `NOTE: letter_height_mm is under 16 mm (5/8 in); ADA 703.2.5 asks raised characters at least that tall, measured on the capital I.`
- **Fix:** raise `letter_height_mm` to 16 or more.

### The sign shows a sample's wording instead of yours

- **On MakerWorld:** no message. The letter plate reads RESTROOM, EXIT, STAIRS
  or ROOM 101 whatever you typed, because a sample sign is picked.
- **In desktop OpenSCAD:** the preview shows `SAMPLE SIGN IN USE` in orange, and
  the console prints
  `NOTE: sample_sign is {name}; text_line_N and braille_line_N are ignored.`
- **Fix:** set `sample_sign` to `Type my own`.

### Letter settings outside the ADA figures

- **On MakerWorld:** nothing — the sign renders fine, so check the two dials
  directly.
- **In desktop OpenSCAD:** the preview shows nothing, and the console prints:
  - `NOTE: letter_raise_mm is under 0.8 mm (1/32 in); ADA 703.2.1 asks raised characters at least that high.`
    when `letter_raise_mm` is under 0.8.
  - `NOTE: letter_line_spacing_pct is outside 135 to 170; ADA 703.2.8 asks the baselines of raised letter lines 135 to 170 percent of the letter height apart.`
    when the sign has two or more lines of letters.
- **Fix:** set `letter_raise_mm` to 0.8 or more, and `letter_line_spacing_pct`
  from 135 to 170.

### The braille plate's fins fall over, or the bridges break mid-print

Raise `bridge_contact_mm` toward 0.4 mm, raise `bridge_count` (default 4), or
lower `fin_interval_mm` (default 25 mm) so more fins share the load.

### The fins will not snap off cleanly

Lower `bridge_contact_mm` toward 0.2 mm, or reduce `bridge_width_mm` /
`bridge_height_mm` (both default 0.5 mm).

### The dots feel rough

Print the braille plate at 0.1 mm layers and slow the outer wall to 30–40 mm/s.
If they are still rough, try `dot_shape` = `Cone`, which some printers render
more cleanly than a dome. Cone is a pointed dot with a flat top, not the domed
shape ADA 703.3.1 asks for, so use it only if `Rounded` prints badly.

### The two plates do not line up when mounted

The split border is the alignment aid — the vertical side rails should be
continuous from the letter plate down through the braille plate. If they are not,
the plates were rendered at different `sign_width_mm` values, or `auto_fit`
resized one of them. Render both plates from the same parameter set, and if you
are exporting them separately, change nothing except `sign_part` between the two
exports.

## 8. Alternative: OpenSCAD Assistive Forge

If the MakerWorld customizer is hard to use with your screen reader — or you
would rather not create an account — the same generator runs in
**[OpenSCAD Assistive Forge](https://openscad-assistive-forge.pages.dev/)**,
an accessibility-first browser customizer. Deep link straight to this model:

<https://openscad-assistive-forge.pages.dev/?example=braille-sign>

What the Forge does that MakerWorld cannot:

- **It translates your braille for you.** Type plain English and liblouis —
  compiled to WebAssembly and running on your own device — produces Unicode
  braille. MakerWorld's customizer has no translator, so there you must paste
  braille you translated elsewhere. This model's Forge default is
  **UEB Grade 2** (`en-ueb-g2.ctb`), the contracted grade conventional for
  permanent signage; UEB Grade 1 and US Grade 1 and 2 are in the same picker, and
  there is a manual Unicode braille editor if you want to override a translation
  by hand.
- **The interface is built for screen readers and keyboards.** Live status
  announcements, a documented keyboard map matching OpenSCAD desktop (F4
  preview, F5/F6 render, F7 download), light/dark/high-contrast themes, and a
  Basic mode that hides the advanced parameters.
- **Presets** you can save, reload, and share as a link.
- **It works offline.** Installable as a desktop app; after the first visit the
  renderer, the braille tables, and this model are cached locally.
- **Filenames describe the model.** A sign reading "Exit" downloads as
  `Braille Sign Exit.stl` rather than a hash.

Nothing leaves your device in either tool: MakerWorld renders on its servers,
the Forge renders in your browser with OpenSCAD compiled to WebAssembly.

The braille card and braille charm generators are in the Forge too, under the same
**Braille Card Customizer** program.

## 9. Resources

- [2010 ADA Standards for Accessible Design](https://archive.ada.gov/) — §703 is
  the signage section
- [Branah braille translator](https://www.branah.com/braille-translator) — set
  the output to Unicode Braille and choose Grade 2 Braille for signage; its own
  page calls its Grade 2 a work in progress
- [BANA *Size and Spacing of Braille Characters*](https://brailleauthority.org/size-and-spacing-braille-characters)
- [The Rules of Unified English Braille (ICEB)](https://iceb.org/ueb.html)
- [ISO 17049:2013 — Application of braille on signage, equipment and appliances](https://www.iso.org/standard/58090.html)
- [Round Table *Guidelines for Producing Accessible 3D Prints* (2024)](https://printdisability.org/guidelines/3d-prints/)
  — the published standard for tactile print design, including a Blind Makers
  section
- [Smith-Kettlewell *3D Printing for Blind & Low Vision Makers*](https://www.ski.org/technical-file/3d-printing-for-bvi-makers/)
  — printer and slicer guidance for the part of the workflow this model cannot
  cover
- [The full guide](guides/full-guide.md) — every dial, warning and note of this
  generator, for desktop OpenSCAD
- [This project on GitHub](https://github.com/BrennenJohnston/braille-sign-openscad)
- For a sign that will be installed in a public building, work with a
  **UEB-certified transcriber** and verify the installation against §703
  yourself.

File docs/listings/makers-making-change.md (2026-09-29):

# Makers Making Change submission packet

No submission form was found on the Makers Making Change site on 2026-09-28.
The contact routes are the email address info@makersmakingchange.com and the
site's contact page, <https://www.makersmakingchange.com/contact>, which the
OpenAT template's "Contact Us" section links. The owner sends the email at the
end of this page; nothing here has been sent.

## The device

The Braille Sign STL Generator makes a two-part tactile room sign: a letter
plate with the words in raised capital letters, and a braille plate with the
same words in braille, mounted touching so their raised borders join into one
frame. It is one parametric OpenSCAD file with a Customizer in four beginner
Steps, four ready-to-print sample signs, and checks that hold the braille to the
figures of ADA Table 703.3.1. The letter plate prints flat and the braille plate
leans back at 75 degrees on break-away fins, so both print on an ordinary FDM
printer without slicer supports.

> **ADA note.** The defaults follow the published §703 figures, but this tool
> does **not** guarantee compliance. Real signage has requirements this
> generator does not model — mounting height and location, contrast, glare,
> character width ratios, and the 9.5 mm (3/8 in) minimum braille offset below
> the raised text. Verify against the standard before installing.

## Who it helps

The sign is for everyone who reads a door: a braille reader, a reader who finds
the raised letters with their fingers, and a sighted reader all get the same
words from one sign. It helps the makers, teachers and facilities staff who put
up room signs, and the [User Guide](../guides/user-guide.md) says in plain
words where ADA 703.4 puts a sign. The generator also runs in the OpenSCAD
Assistive Forge, a browser customizer built for screen readers and keyboards
that translates the braille with liblouis, so a blind maker can make a sign
without a sighted person driving the software.

**An automatic translator is not a certified transcriber.** The guides say to
have the braille of a sign in a public building checked by a transcriber
certified in Unified English Braille (UEB).

## The OpenAT documents

| Document | Path in this repository |
|---|---|
| Design Rationale | [`docs/guides/design-rationale.md`](../guides/design-rationale.md) |
| Maker Guide | [`docs/guides/maker-guide.md`](../guides/maker-guide.md) |
| User Guide | [`docs/guides/user-guide.md`](../guides/user-guide.md) |
| Bill of Materials | [`docs/guides/bom.md`](../guides/bom.md) |
| Changelog | [`CHANGELOG.md`](../../CHANGELOG.md) |
| OKH manifest | [`okh.yml`](../../okh.yml) |
| README in the OpenAT order | [`README.md`](../../README.md) |

Beyond the template: a one-page [quick start](../guides/quick-start.md) and a
[full guide](../guides/full-guide.md) to every dial and message.

## Files

- [`Braille_Sign_STL_Generator.scad`](../../Braille_Sign_STL_Generator.scad):
  the generator, one self-contained OpenSCAD file.
- [`Braille_Sign_STL_Generator.json`](../../Braille_Sign_STL_Generator.json):
  presets that OpenSCAD's Customizer loads beside it.
- The eight STLs in [the `stl/` folder](../../stl/README.md), both plates of
  each sample sign:
  - `restroom-letter-plate.stl` and `restroom-braille-plate.stl`
  - `exit-letter-plate.stl` and `exit-braille-plate.stl`
  - `stairs-letter-plate.stl` and `stairs-braille-plate.stl`
  - `room-101-letter-plate.stl` and `room-101-braille-plate.stl`

## License

The design, the code and the documents are under PolyForm Noncommercial 1.0.0
([`LICENSE`](../../LICENSE)). It lets anyone use, change and share them for any
noncommercial purpose, including personal projects and use by charities,
schools and public health, safety and research organizations, as long as the
copyright notice travels with them. It gives no right to use them for a
commercial purpose, such as selling the files or signs made from them.

The OpenAT template suggests open-source licenses and allows a maker's own
choice; this license limits commercial use, so it is not an open-source license.

## Photos

The seven photos of the shot list are to come: both plates mounted with a hand
on the braille (the cover), the two plates apart, the braille plate on the bed
with its fins, the letter plate lying flat, a close-up of the dots, calipers on
a letter, and a sign of several lines. They enter `docs/images/` once the owner
has chosen them.

## Readiness

From [`okh.yml`](../../okh.yml), where both are marked as the owner's claim to
confirm before submitting: documentation readiness ODRL-3 and technology
readiness OTRL-4. Its attestation reads: "Rendered and checked by the
repository's tests; a test print of this version by the designer is pending; no
third-party certification has been performed."

## Checklist against the OpenAT template

| Template item | Here |
|---|---|
| Design Rationale | `docs/guides/design-rationale.md` |
| Maker Guide | `docs/guides/maker-guide.md` |
| Bill of Materials | `docs/guides/bom.md` |
| User Guide | `docs/guides/user-guide.md` |
| Changelog | `CHANGELOG.md` |
| Open Know-How manifest | `okh.yml` |
| README sections in the template's order | `README.md`, with one more section, How to use it |
| Documentation folder | `docs/` and `docs/guides/` |
| Design files: CAD | `Braille_Sign_STL_Generator.scad` and `Braille_Sign_STL_Generator.json` |
| Design files: PCB | not applicable: no electronics |
| Build files: 3D printing | `stl/` |
| Build files: PCB | not applicable: no electronics |
| Firmware | not applicable: no firmware; the generator is a design file |
| LICENSES folder | `LICENSE` at the root, one license for everything |
| Photos folder | to come: the shot list, then `docs/images/` |
| Attribution to the OpenAT template | `README.md`, section Attribution |
| Assistive Device Library link | to come: once Makers Making Change lists the device |

## The email

Subject: Braille Sign STL Generator, a two-part tactile room sign for the
Assistive Device Library

> Hello Makers Making Change team,
>
> I would like to offer the Braille Sign STL Generator for your Assistive Device
> Library. It makes a two-part tactile room sign: raised capital letters on one
> plate and the same words in braille on a second plate below, which join into
> one framed sign on the wall. One OpenSCAD file with a four-step Customizer and
> four ready-to-print samples (Restroom, Exit, Stairs and Room 101) covers most
> doors, and the OpenSCAD Assistive Forge runs it in a browser for screen-reader
> users and translates the braille. An automatic translator is not a certified transcriber, so the guides ask for a
> transcriber's check on public signs.
>
> The repository follows your OpenAT template: Design Rationale, Maker Guide,
> User Guide, Bill of Materials, Changelog, okh.yml and the README's order.
>
> https://github.com/BrennenJohnston/braille-sign-openscad
>
> Two things to know. The license is PolyForm Noncommercial 1.0.0, which allows
> noncommercial use and sharing but not commercial use. A test print of the
> current version is still pending. The dimensions follow the 2010 ADA
> Standards' sign figures, with no claim of compliance.
>
> What would you need from me to list it?
>
> Brennen Johnston

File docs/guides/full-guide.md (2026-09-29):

# Full guide

This guide explains how the Braille Sign STL Generator builds a sign, what
every dial does, and every message it can show you. It is for makers who want
to change more than the four Steps. If you are making your first sign, start
with the [quick start](quick-start.md) instead.

Every dial is named exactly as it appears in the Customizer, OpenSCAD's panel
of settings. Sizes are in millimeters, with inches where the ADA Standards
state inches.

## How the sign is built

A sign is two plates that print separately and hang one above the other.

The **letter plate** is a flat plate `plate_thickness_mm` thick (3 mm by
default) with the raised letters on top, `letter_raise_mm` high (0.8 mm). The
lines of letters form one block centered on the plate, and each line is
centered on its own. It always prints flat, letters up.

The **braille plate** is first built flat: the plate, its raised border and
the braille dots. For printing it is spun around to face the other way and
leaned back to `face_angle_deg` (75 degrees by default), which keeps the
braille reading left to right and its bottom rail at the bottom. A plate leaned onto the bed would touch it along a knife edge, so
the generator sinks it 0.6 mm into the bed and cuts it flat there, which gives
the bottom edge a real strip of first layer. With `print_orientation` set to
`Flat`, the plate prints dots up instead.

Behind the leaning plate stand break-away **support fins**: thin triangles,
one at each end and more at a steady interval between. Each fin joins the
back of the plate through a few small **bridges**, which snap when you flex
the fin, and sits on a thin **brim** that holds it to the bed. The brim stops
just short of the plate, so the two never touch in the file.

The raised border is **split** between the plates: the letter plate carries
the top rail and both side rails, and the braille plate carries the bottom
rail and both side rails. When you mount the plates touching, letters above
braille, the rails join into one frame around the whole sign.

**Auto-fit.** With `auto_fit` on `Yes`, the three size dials are minimums and
the plates grow to fit what you typed. The letters keep 4 mm of space inside
the border rails, and the braille keeps `braille_clearance_mm` (9.5 mm), the
space ADA 703.3.2 asks between braille and a raised border. Both plates always
share one width, so their side rails line up: the wider of the letters' and
the braille's needs sets it. The letters' width is an estimate, worked out
from a table of every character's width in Liberation Sans, the font the file
uses; on the two test lines it measured, it came out 0.45 % and 1.16 % wider
than the printed letters, never narrower.

Seen from straight above, the default sign's two plates lie on the bed the way
they hang on the wall: the letter plate at the back and the braille plate in
front, leaning on its fins. From this angle the braille shows as a row of dots,
and the flat tops of the raised letters barely stand out from the plate.

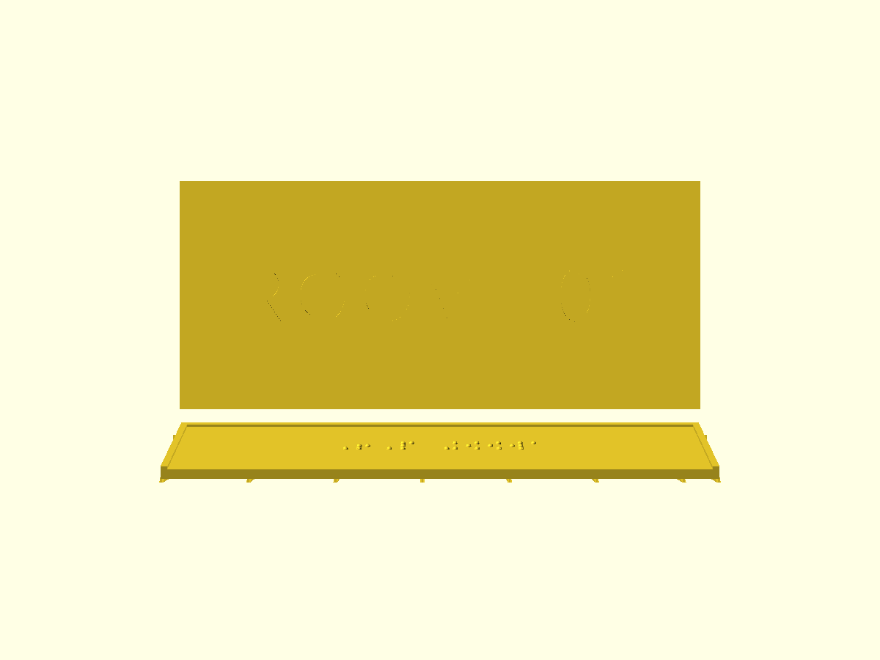
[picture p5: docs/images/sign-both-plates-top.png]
The default sign's two plates seen from straight above, as they lie on the print bed. The letter plate is at the top; its raised ROOM 101 shows only as faint outlines from this angle. Below it the braille plate, leaning back on its fins, shows its raised border and one row of braille dots across th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


## The four Steps

The Customizer opens with four tabs a beginner fills in from top to bottom.
Every tab after them starts with "Advanced -".

**Step 1 - Pick a sample sign or type your own.** `sample_sign` picks one of
the built-in signs (Restroom, Exit, Stairs or Room 101), which brings its own
wording and braille, or `Type my own`, which uses the six text lines below it.
Each text line becomes one line of raised letters, top to bottom.

**Step 2 - Braille, pasted from a translator.** Each braille line holds the
braille for the text line with the same number, as Unicode braille
characters. A sample sign ignores these lines. See
[The sample signs](#the-sample-signs) for where the samples' braille comes
from, and the quick start's
[Translating your wording](quick-start.md#translating-your-wording) for how to
make your own.

**Step 3 - What to export.** `sign_part` chooses both plates together or one
at a time, and `print_orientation` chooses whether the braille plate leans on
fins or lies flat. The plates print best with different settings, so export
them one at a time for a real print.

**Step 4 - Size.** This tab holds `auto_fit` and three size dials. Left on
`Yes`, auto-fit makes the plates as big as the wording needs, and the
console's first line reports the final size.

## Every dial

Each dial below is in the Customizer's order, with what it changes, its
default and range, and the ADA figure where one applies. The Customizer keeps
a dial inside its range. A value set outside it from the command line or a
preset file renders without any check, except for the braille dials, whose
checks stop the render with the message quoted under each one.

The dials of **Step 1 - Pick a sample sign or type your own**:

### `sample_sign`

Picks a ready-made sign or your own wording. A sample replaces all six text
lines and all six braille lines with its own; every other dial still applies.

- Default: `Type my own`. Options: `Type my own`, `Restroom`, `Exit`, `Stairs`,
  `Room 101`.
- With a sample picked, the preview shows SAMPLE SIGN IN USE in orange and the
  console prints a note naming the sample.

### `text_line_1`

The first line of raised letters. `force_uppercase` turns a to z into
capitals as the letters are made; the font is Liberation Sans, a sans serif,
as ADA 703.2.3 asks.

- Default: `Room 101`. Any text; ignored while a sample is picked.
- The line is centered on the plate. With auto-fit on, a line too wide for the
  plate widens both plates instead.

### `text_line_2`

The second line of raised letters, below the first.

- Default: empty.
- An empty line after the last filled line adds nothing. An empty line between
  two filled lines keeps its place, so it leaves a gap in the sign.

### `text_line_3`

The third line of raised letters. Works as `text_line_2` does. Default: empty.

### `text_line_4`

The fourth line of raised letters. Works as `text_line_2` does. Default: empty.

### `text_line_5`

The fifth line of raised letters. Works as `text_line_2` does. Default: empty.

### `text_line_6`

The sixth line of raised letters. Works as `text_line_2` does. Default: empty.

The dials of **Step 2 - Braille, pasted from a translator**:

### `braille_line_1`

The braille for `text_line_1`, as Unicode braille: the dot-pattern characters
U+2800 to U+28FF, one character per braille cell. The blank cell, U+2800, is
the space between words.

- Default: the braille for "Room 101", starting with a capital sign. The
  Room 101 sample's braille has none; see [The sample signs](#the-sample-signs).
- Any other character, including an ordinary space or ASCII braille, prints no
  dots, and the preview shows NOT BRAILLE IN LINE 1.
- The braille lines line up on their left ends, and the block they make is
  centered on the plate by its longest line.

### `braille_line_2`

The braille for `text_line_2`. Works as `braille_line_1` does. Default: empty.
An empty line between two filled lines keeps its place, as with the text
lines.

### `braille_line_3`

The braille for `text_line_3`. Works as `braille_line_1` does. Default: empty.

### `braille_line_4`

The braille for `text_line_4`. Works as `braille_line_1` does. Default: empty.

### `braille_line_5`

The braille for `text_line_5`. Works as `braille_line_1` does. Default: empty.

### `braille_line_6`

The braille for `text_line_6`. Works as `braille_line_1` does. Default: empty.

The dials of **Step 3 - What to export**:

### `sign_part`

Which plates the render holds.

- Default: `Both`. Options: `Both`, `Letter plate`, `Braille plate`.
- `Both` lays the letter plate at the back and the braille plate in front,
  `plate_gap_mm` apart, the way they hang on the wall. Export each plate alone
  to print it with its own settings.

### `print_orientation`

How the braille plate prints. The letter plate always prints flat.

- Default: `Angled`. Options: `Angled`, `Flat`.
- `Angled` leans the plate back to `face_angle_deg` on break-away fins, which
  gives the crispest dots. `Flat` prints the plate dots up, with no fins.

The dials of **Step 4 - Size**:

### `auto_fit`

Whether the plates grow to fit the wording.

- Default: `Yes`. Options: `Yes`, `No`.
- `Yes` treats the three size dials as minimums and grows the plates so every
  line fits with its space (4 mm for letters, `braille_clearance_mm` for
  braille) inside the border. `No` keeps the exact sizes and warns when
  something does not fit.

### `sign_width_mm`

The width of both plates, or with auto-fit on, the smallest width they may
have.

- Default: 160. Range: 60 to 300 mm, in steps of 1.
- With auto-fit on, the width is the largest of this dial, the widest line of
  letters plus its space each side, and the widest braille line plus its space
  each side.

### `letter_plate_height_mm`

The height of the letter plate, or with auto-fit on, its smallest height.

- Default: 70. Range: 30 to 200 mm, in steps of 1.
- With auto-fit on, the plate grows to the block of letters plus 4 mm inside
  the border, top and bottom. The block is one letter height plus one line
  spacing for each extra line.

### `braille_plate_height_mm`

The height of the braille plate, or with auto-fit on, its smallest height.

- Default: 40. Range: 25 to 150 mm, in steps of 1.
- With auto-fit on, the plate grows to the braille block plus
  `braille_clearance_mm` inside the border, top and bottom.

The dials of **Advanced - Plates and border**:

### `plate_thickness_mm`

The thickness of both plates, not counting the letters, dots or border on top.

- Default: 3. Range: 2 to 8 mm, in steps of 0.5.
- The raised letters and the border start at this height, which is where a
  filament change for contrast goes.

### `plate_gap_mm`

The space on the print bed between the letter plate and the braille plate
when `sign_part` is `Both`.

- Default: 8. Range: 2 to 30 mm, in steps of 1.
- It changes nothing when you export one plate at a time.

### `add_border`

Whether the plates get the split raised border.

- Default: `Yes`. Options: `Yes`, `No`.
- With `No`, neither plate has rails, and auto-fit measures its spaces from
  the plate edges instead of the rails.

### `border_width_mm`

The width of each border rail.

- Default: 2. Range: 0.5 to 6 mm, in steps of 0.5.
- Auto-fit adds it to the letters' and the braille's spaces, so a wider rail
  makes the plates bigger.

### `border_height_mm`

How far the border rails rise above the plate face.

- Default: 0.8. Range: 0.2 to 2 mm, in steps of 0.1.
- ADA 703.3.2 asks 9.5 mm (3/8 in) between braille and a raised border;
  `braille_clearance_mm` keeps it.

The dials of **Advanced - Raised letters, ADA 703.2**:

### `force_uppercase`

Turns the letters a to z into capitals as the sign is made. Accented letters
and other characters stay as typed.

- Default: `Yes`. Options: `Yes`, `No`.
- ADA 703.2.2: characters shall be uppercase.

### `letter_height_mm`

The height of the raised capital letters, measured on the printed capital I,
as ADA measures it. Liberation Sans draws its I at 0.9555 of the font size,
so the file divides this dial by 0.9555 before it sets the size.

- Default: 16. Range: 12 to 50 mm, in steps of 0.5.
- Measured at 16: the I and the other flat-topped capitals tried (E, H, M, R,
  T) print 16.000 mm tall, and round ones (O, S) about 0.47 mm taller; the O is
  99.2 % as wide as the I is tall, and the I's stroke is 13.6 % of its height.
- ADA 703.2.5: 16 mm (5/8 in) minimum and 51 mm (2 in) maximum, on the
  uppercase I; 13 mm (1/2 in) is allowed where separate raised and visual
  characters carry the same information. ADA 703.2.4 asks the O's width to be
  55 to 110 % of the I's height, and 703.2.6 the I's stroke at most 15 %.
- Under 16 on a sign with text: the preview shows LETTERS UNDER 16 MM and the
  console prints a note. The sign still renders.

### `letter_raise_mm`

How far the letters rise off the plate.

- Default: 0.8. Range: 0.4 to 2 mm, in steps of 0.05.
- ADA 703.2.1: 0.8 mm (1/32 in) minimum.
- Under 0.8 on a sign with text: the console prints a note.

### `letter_line_spacing_pct`

The distance from one line's baseline to the next, as a percent of the letter
height.

- Default: 135. Range: 100 to 200 percent, in steps of 5.
- ADA 703.2.8: 135 to 170 percent of the raised character height.
- Outside 135 to 170 on a sign with two or more lines of letters: the console
  prints a note.

### `letter_spacing_factor`

Spreads or tightens the letters. 1 is the font's own spacing; 1.1 adds a
little air.

- Default: 1.1. Range: 0.8 to 2, in steps of 0.05.
- ADA 703.2.7: for letters with square sides, as these are, 3.2 mm (1/8 in)
  minimum and four times the stroke width maximum between the closest points
  of two neighbors. Measured at 1.1 and 16 mm: two capital I's sit 4.939 mm
  apart, inside 3.2 to 8.68 mm. The generator does not check other letter
  pairs.

The dials of **Advanced - Braille spacing, ADA 703.3**:

### `braille_cell_spacing_mm`

The distance between the centers of matching dots in neighboring cells.

- Default: 6.5. Range: 6.1 to 7.6 mm, in steps of 0.1. 6.5 is inside the
  range of ISO 17049, the international standard for braille on signs, too.
- ADA Table 703.3.1: 6.1 to 7.6 mm (0.241 to 0.300 in).
- Outside the range, the render stops:
  `braille_cell_spacing_mm must be 6.1 to 7.6 mm (ADA 703.3.1)`

### `braille_line_spacing_mm`

The distance between the centers of matching dots in a cell and the cell
directly below it, on the next braille line.

- Default: 10. Range: 10.0 to 10.2 mm, in steps of 0.1.
- ADA Table 703.3.1: 10 to 10.2 mm (0.395 to 0.400 in).
- Outside the range, the render stops:
  `braille_line_spacing_mm must be 10.0 to 10.2 mm (ADA 703.3.1)`

### `braille_dot_spacing_mm`

The distance between the centers of two dots in the same cell.

- Default: 2.5. Range: 2.3 to 2.5 mm, in steps of 0.1.
- ADA Table 703.3.1: 2.3 to 2.5 mm (0.090 to 0.100 in).
- Outside the range, the render stops:
  `braille_dot_spacing_mm must be 2.3 to 2.5 mm (ADA 703.3.1)`

### `braille_clearance_mm`

The clear space auto-fit keeps between the outer edges of the braille dots
and the border rails. The braille plate's top edge has no rail, so the braille
sits the rail's width farther from it.

- Default: 9.5. Range: 9.5 to 20 mm, in steps of 0.5.
- ADA 703.3.2: braille 9.5 mm (3/8 in) minimum from raised borders and from
  any other tactile characters. Measured on a six-line sign: 9.505 mm from the
  bottom rail.
- With auto-fit off, braille that fits the plate but not with this space shows
  BRAILLE TOO CLOSE TO BORDER.
- Under 9.5, the render stops:
  `braille_clearance_mm is below the ADA 703.3.2 minimum of 9.5 mm`

The dials of **Advanced - Braille dot shape**:

### `dot_shape`

The shape of every braille dot.

- Default: `Rounded`. Options: `Rounded`, `Cone`.
- `Rounded` is a short base topped by a dome: the domed or rounded dot ADA
  703.3.1 asks for. `Cone` is a pointed dot with a small flat top, which is
  not the ADA shape; use it only if Rounded prints badly on your printer. Each
  shape ignores the other shape's dials.

### `rounded_dot_base_diameter`

For Rounded dots: the diameter where the dot meets the plate.

- Default: 1.6. Range: 1.5 to 1.6 mm, in steps of 0.01.
- ADA Table 703.3.1: dot base diameter 1.5 to 1.6 mm (0.059 to 0.063 in).
- Outside the range, the render stops:
  `rounded_dot_base_diameter must be 1.5 to 1.6 mm (ADA 703.3.1 dot base diameter)`

### `rounded_dot_base_height`

For Rounded dots: the height of the base below the dome. The base narrows
from `rounded_dot_base_diameter` to `rounded_dot_dome_diameter`.

- Default: 0.35. Range: 0.1 to 0.5 mm, in steps of 0.01.
- ADA Table 703.3.1: the whole dot, base plus dome, 0.6 to 0.9 mm (0.025 to
  0.037 in) tall. The default dot is 0.7 mm; it sinks 0.02 mm into the face to
  fuse with it, and measured on the plate it stands 0.676 mm proud.
- Outside the range, the render stops:
  `rounded_dot_base_height must be 0.1 to 0.5 mm`
- If base plus dome falls outside 0.6 to 0.9, the render stops:
  `rounded dot total height must be 0.6 to 0.9 mm (ADA 703.3.1 dot height)`

### `rounded_dot_dome_diameter`

For Rounded dots: the diameter of the dome where it sits on the base.

- Default: 1.4. Range: 1.0 to 1.6 mm, in steps of 0.01.
- Outside the range, the render stops:
  `rounded_dot_dome_diameter must be 1.0 to 1.6 mm`
- Wider than the base, the render stops:
  `rounded_dot_dome_diameter must not exceed rounded_dot_base_diameter`

### `rounded_dot_dome_height`

For Rounded dots: the height of the dome.

- Default: 0.35. Range: 0.2 to 0.8 mm, in steps of 0.01.
- Base plus dome must total 0.6 to 0.9 mm, the ADA 703.3.1 dot height.
- Outside the range, the render stops:
  `rounded_dot_dome_height must be 0.2 to 0.8 mm`

### `cone_dot_base_diameter`

For Cone dots: the diameter where the dot meets the plate.

- Default: 1.5. Range: 1.5 to 1.6 mm, in steps of 0.01.
- ADA Table 703.3.1: dot base diameter 1.5 to 1.6 mm.
- Outside the range, the render stops:
  `cone_dot_base_diameter must be 1.5 to 1.6 mm (ADA 703.3.1 dot base diameter)`

### `cone_dot_height`

For Cone dots: the height of the dot.

- Default: 0.8. Range: 0.6 to 0.9 mm, in steps of 0.01.
- ADA Table 703.3.1: dot height 0.6 to 0.9 mm.
- Outside the range, the render stops:
  `cone_dot_height must be 0.6 to 0.9 mm (ADA 703.3.1 dot height)`

### `cone_dot_top_diameter`

For Cone dots: the diameter of the small flat top.

- Default: 0.4. Range: 0.3 to 1.0 mm, in steps of 0.01.
- Outside the range, the render stops:
  `cone_dot_top_diameter must be 0.3 to 1.0 mm`
- As wide as the base or wider, the render stops:
  `cone_dot_top_diameter must be smaller than cone_dot_base_diameter`

The dials of **Advanced - Braille plate lean and support fins**. They change
nothing when `print_orientation` is `Flat`.

### `face_angle_deg`

The angle between the braille plate and the bed when it prints leaning.

- Default: 75. Range: 60 to 90 degrees, in steps of 1.
- 75 to 90 reads best, and 75 needs no slicer supports. This is the print
  angle only: the plate hangs flat on the wall.

### `support_fins`

Whether break-away fins hold the leaning plate up.

- Default: `Yes`. Options: `Yes`, `No`.
- With `No`, the plate leans with nothing behind it, so your slicer would need
  supports.

### `fin_interval_mm`

The space between fins across the plate. A fin always stands at each end.

- Default: 25. Range: 1 to 200 mm, in steps of 0.5.
- The default 160 mm sign gets eight fins. More fins hold the plate more
  firmly.

### `fin_offset_mm`

The gap between the back of the leaning plate and the fins. The bridges cross
it.

- Default: 1.0. Range: 0.2 to 10 mm, in steps of 0.05.

### `fin_thickness_mm`

The thickness of each fin.

- Default: 1.2. Range: 0.2 to 10 mm, in steps of 0.05.

### `fin_height_frac`

The height of each fin as a fraction of the leaning plate's height above the
bed. 1 is full height.

- Default: 1.0. Range: 0.05 to 1, in steps of 0.01.

### `bridge_count`

The number of small bridges joining each fin to the plate. They spread evenly
from about 2 mm above the bed to just below the top of the fin.

- Default: 4. Range: 1 to 60, in steps of 1.

### `bridge_width_mm`

The width of each bridge, measured across the plate.

- Default: 0.5. Range: 0.2 to 8 mm, in steps of 0.05.

### `bridge_height_mm`

The height of each bridge.

- Default: 0.5. Range: 0.2 to 8 mm, in steps of 0.05.

### `bridge_contact_mm`

How far each bridge reaches into the back of the plate.

- Default: 0.3. Range: 0.1 to 3 mm, in steps of 0.05.
- 0.3 to 0.4 snaps off clean. Raise it toward 0.4 if fins fall during a
  print; lower it toward 0.2 if they will not snap off.

### `brim_width_mm`

The width of the brim around the foot of each fin. 0 turns the brims off.

- Default: 2.0. Range: 0 to 25 mm, in steps of 0.25.

### `brim_thickness_mm`

The thickness of the fin brims, about one or two printed layers.

- Default: 0.2. Range: 0.1 to 3 mm, in steps of 0.05.

The dials of **Advanced - Warnings and rendering**:

### `show_warnings`

Whether problems show as text beside the sign in the preview. The text is
drawn as background, so it never reaches a render or an export.

- Default: `Yes`. Options: `Yes`, `No`.
- The console prints the same problems either way.

### `render_quality`

How smooth the rounded dots' domes are: the number of sides each dome is
drawn with.

- Default: `Medium`. Options: `Low` (24), `Medium` (32), `High` (64).
- High renders a little slower. The letters' curves use a fixed 32 sides.

### `dot_segments`

How many flat sides draw each dot's round outline, for both dot shapes: the
base of a Rounded dot and the whole of a Cone dot.

- Default: 40. Range: 8 to 64, in steps of 1.
- Higher is smoother and slower.

## The sample signs

`sample_sign` offers these four signs. Their braille is Unified English
Braille (UEB) Grade 2 from liblouis, an open-source braille translator,
written into `scripts/sample_signs.json` by
`scripts/generate_sample_braille.mjs`; a test checks that the file's own
tables match that data.

| Sample | Raised letters | Braille | Cells |
|---|---|---|---|
| Restroom | RESTROOM | ⠗⠑⠌⠗⠕⠕⠍ | 7 |
| Exit | EXIT | ⠑⠭⠊⠞ | 4 |
| Stairs | STAIRS | ⠌⠁⠊⠗⠎ | 5 |
| Room 101 | ROOM 101 | ⠗⠕⠕⠍⠀⠼⠁⠚⠁ | 9 |

The raised letters are capitals, as ADA 703.2.2 asks. The braille has no
capital sign, because ADA 703.3.1 allows the braille capital sign only before
the first word of a sentence, a name, a single letter, initials or an acronym,
and a room name on a sign is none of those.

**An automatic translator is not a certified transcriber.** For a sign in a
public building, have a transcriber certified in UEB check the braille before
you print.

## Warnings and notes

When something is wrong, the generator says so in two places. In the desktop
preview (F5), red words lie flat just beyond the far edge of the sign, 5 mm
tall and one line per problem; they disappear when you render with F6 and
never reach an export. The console under the preview prints the same problem
with its numbers. `show_warnings` turns the preview words off; the console
lines stay. MakerWorld's Parametric Model Maker shows neither the preview
words nor the console, so the [MakerWorld quick
start](../MAKERWORLD_QUICK_START.md#7-troubleshooting) lists what each problem
looks like there.

In the console texts below, a word in braces, such as `{n}`, stands for the
number or name the console prints.

### Not braille in a braille line

- Preview: `NOT BRAILLE IN LINE {n}`, with the line's number.
- Console: `WARNING: braille_line_{n} contains non-braille characters. Use Unicode braille (U+2800-U+28FF).`
- When: a braille line holds a character outside U+2800 to U+28FF, such as a
  typed letter, ASCII braille or an ordinary space. That character prints no
  dots.
- Fix: paste Unicode braille from a translator. For a space between words, use
  the blank braille cell, U+2800.

### Text too wide

- Preview: `TEXT TOO WIDE`.
- Console: `WARNING: TEXT TOO WIDE: {estimate}/{space} mm (estimated from character advances, so treat it as approximate). Turn on auto_fit, raise sign_width_mm to at least {width}, or shorten the line.`
- When: `auto_fit` is `No` and the widest line of letters is estimated wider
  than the space inside the border.
- Fix, in order: set `auto_fit` to `Yes`; raise `sign_width_mm` to the width
  given; shorten the line.

### Text too tall

- Preview: `TEXT TOO TALL`.
- Console: `WARNING: TEXT TOO TALL: {block}/{space} mm. The raised text block is taller than the letter plate's usable height. Turn on auto_fit, raise letter_plate_height_mm to at least {height}, or remove a line.`
- When: `auto_fit` is `No` and the block of letters is taller than the space
  inside the border.
- Fix, in order: set `auto_fit` to `Yes`; raise `letter_plate_height_mm` to the
  height given; remove a line.

### Braille too wide

- Preview: `BRAILLE TOO WIDE`.
- Console: `WARNING: BRAILLE TOO WIDE: {block}/{space} mm (longest line is {cells} cells). Turn on auto_fit, raise sign_width_mm to at least {width}, or shorten the line.`
- When: `auto_fit` is `No` and the longest braille line is wider than the
  space inside the border.
- Fix, in order: set `auto_fit` to `Yes`; raise `sign_width_mm` to the width
  given; shorten the line.

### Braille too tall

- Preview: `BRAILLE TOO TALL`.
- Console: `WARNING: BRAILLE TOO TALL: {block}/{space} mm. The braille block is taller than the braille plate's usable height. Turn on auto_fit, raise braille_plate_height_mm to at least {height}, or remove a line.`
- When: `auto_fit` is `No` and the braille block is taller than the space
  inside the border.
- Fix, in order: set `auto_fit` to `Yes`; raise `braille_plate_height_mm` to the
  height given; remove a line.

### Braille too close to the border

- Preview: `BRAILLE TOO CLOSE TO BORDER`.
- Console, when the height is short: `WARNING: BRAILLE TOO CLOSE TO BORDER: {block}/{space} mm. ADA 703.3.2 asks {clearance} mm of clear space. Turn on auto_fit, raise braille_plate_height_mm to at least {height}, or remove a line.`
- Console, when the width is short: `WARNING: BRAILLE TOO CLOSE TO BORDER: {block}/{space} mm (longest line is {cells} cells). ADA 703.3.2 asks {clearance} mm of clear space. Turn on auto_fit, raise sign_width_mm to at least {width}, or shorten the line.`
- When: `auto_fit` is `No` and the braille fits inside the border but not with
  `braille_clearance_mm` of space on both sides. Braille that does not fit at
  all shows BRAILLE TOO TALL or BRAILLE TOO WIDE instead.
- Fix, in order: set `auto_fit` to `Yes`; raise the size the console names to
  the value given; remove or shorten a line.

### Letters under 16 mm

- Preview: `LETTERS UNDER 16 MM`.
- Console: `NOTE: letter_height_mm is under 16 mm (5/8 in); ADA 703.2.5 asks raised characters at least that tall, measured on the capital I.`
- When: the sign has text and `letter_height_mm` is under 16.
- Fix: raise `letter_height_mm` to 16 or more. The sign still renders, so a
  smaller sign for a use outside the ADA Standards is your call.

### Sample sign in use

- Preview: `SAMPLE SIGN IN USE`, in orange.
- Console: `NOTE: sample_sign is {name}; text_line_N and braille_line_N are ignored.`
- When: `sample_sign` is set to a sample.
- Fix, if you want your own wording: set `sample_sign` to `Type my own`.

### Notes in the console only

These print to the console and draw nothing in the preview:

- `NOTE: letter_raise_mm is under 0.8 mm (1/32 in); ADA 703.2.1 asks raised characters at least that high.`
  When the sign has text and `letter_raise_mm` is under 0.8.
- `NOTE: letter_line_spacing_pct is outside 135 to 170; ADA 703.2.8 asks the baselines of raised letter lines 135 to 170 percent of the letter height apart.`
  When the sign has two or more lines of letters and the spacing is outside
  135 to 170.
- `NOTE: ADA defaults are recommendations only - this tool does not guarantee compliance. Mount the braille plate at least 9.5 mm (3/8 in) below the raised text.`
  On every render.

Every render also prints the sign's size, and a sign with text prints its
width estimate:

- `Braille sign: {t} text line(s), {b} braille line(s), {w} mm wide, plates {h1} + {h2} mm tall`
- `Text width estimate: {w} mm`

## Old names

Some dials were renamed so that each name says what the dial holds. If you
have a saved preset or a command-line script, change these names:

| Old name | New name | What changed |
|---|---|---|
| `sign_text_1` to `sign_text_6` | `text_line_1` to `text_line_6` | the name only |
| `Line_1` to `Line_6` | `braille_line_1` to `braille_line_6` | the name only |
| `char_height_mm` | `letter_height_mm` | now the printed capital I; multiply an old value by 0.9555 for the same print |
| `line_spacing_pct` | `letter_line_spacing_pct` | the name only |
| `letter_spacing` | `letter_spacing_factor` | the name only |
| `cell_spacing` | `braille_cell_spacing_mm` | default 6.5, was 7.0; range now 6.1 to 7.6 |
| `line_spacing` | `braille_line_spacing_mm` | range now 10.0 to 10.2 |
| `dot_spacing` | `braille_dot_spacing_mm` | range now 2.3 to 2.5 |
| `part_gap_mm` | `plate_gap_mm` | the name only |
| `cone_dot_flat_hat` | `cone_dot_top_diameter` | the name only |
| `cone_segments` | `dot_segments` | the name only; it shapes both dot types |

Three dials are new: `sample_sign`, `braille_clearance_mm` and
`show_warnings`. Two dials changed their values: `add_border` takes `Yes` or
`No` where it took lowercase `yes` or `no`, and `support_fins` takes `Yes` or
`No` where it took `On` or `Off`. The old values count as `No`: an old
preset's `yes` leaves both plates without a border, and its `On` leaves the
braille plate without fins.

OpenSCAD ignores a name it does not know, without any message: an old name in
a preset file or on the command line leaves that dial at its default. Check
the console's size line after you convert a preset.

## The command line

OpenSCAD can make a sign without its window. On Windows, run the console
program, `openscad.com`, from the OpenSCAD folder; on other systems the
command is `openscad`.

Set a dial with `-D name=value`. A text value needs double quotes inside the
argument, so wrap the whole argument in single quotes in a Bash shell:

```bash
openscad -D 'sample_sign="Restroom"' -D 'sign_part="Letter plate"' -o restroom-letter-plate.stl Braille_Sign_STL_Generator.scad
openscad -D 'sample_sign="Exit"' -D letter_height_mm=20 -o exit-20-mm.stl Braille_Sign_STL_Generator.scad
```

Windows PowerShell 5.1 splits a `-D` value that has a space in it into two
arguments, and OpenSCAD then prints its help instead of a sign; use Git Bash
or another Bash shell for those.

The presets file, `Braille_Sign_STL_Generator.json`, holds named sets of
dials. Pick one with `-p` for the file and `-P` for the set's name:

```bash
openscad -p Braille_Sign_STL_Generator.json -P "Default Sign (both plates)" -o sign.stl Braille_Sign_STL_Generator.scad
```

`--check-parameter-ranges=true` checks the values given to OpenSCAD's own
building blocks, not the Customizer's sliders: a `-D` value outside a slider
renders without a message. The braille dials are held instead by checks in
the file that stop the render, quoted under each dial above.

Two more options help in scripts. `--hardwarnings` stops the render on any
warning from OpenSCAD itself (the generator's own messages start with `ECHO:`
and do not count), and `--export-format binstl` writes a smaller, binary STL.

The console's `Text width estimate` line gives the width auto-fit planned for
the widest line of letters, from the character table described in
[How the sign is built](#how-the-sign-is-built). It errs on the wide side, so
the plate is never too narrow for the letters.

## Tests and CI

The tests live in `tests/` and run with `python -m pytest tests`. The ones
marked `requires_openscad` render the sign and need OpenSCAD installed; the
rest only read files.

- `tests/test_customizer.py`: the dropdowns are well formed, and the presets
  file names only real dials and holds no personal text.
- `tests/test_source_guards.py`: one self-contained file, the pinned font, the
  three export choices, six text and braille line pairs, the tab layout,
  dropdown labels without parentheses, and the braille sliders inside ADA
  Table 703.3.1.
- `tests/test_sample_signs.py`: the sample data is well formed and matches the
  dropdown and the file's tables.
- `tests/test_ada_figures.py`: the capital I height, the width estimate within
  2 %, the braille's 9.5 mm clearance, and the character table against its
  data file.
- `tests/test_render_smoke.py`: each plate renders as one solid, and the
  preview warnings never reach an export.
- `tests/test_release_stls.py`: `stl/README.md` lists every shipped STL, and
  the shipped Restroom letter plate still matches a fresh render.
- `tests/test_full_guide_covers_every_dial.py`: this guide names every dial,
  quotes every warning and note, and matches the sample data.
- `tests/test_docs_gate.py`: the README and every page under `docs/` meet the
  documentation rules that `scripts/check_docs.py` checks.

`scripts/scad-check.ps1` renders the default sign with strict warnings and
prints `CHECK PASSED` or `CHECK FAILED`. `scripts/README.md` lists the other
scripts. The continuous integration workflow, `.github/workflows/ci.yml`,
runs on every pull request: a lint check, then every test that needs no
OpenSCAD, then `tests/test_render_smoke.py` with the OpenSCAD nightly. Run the
other tests marked `requires_openscad` yourself before you open a pull
request.

## What the generator does not do

The generator makes two plates. It cannot see where you put them, what color
they are, or whether the braille says what you meant:

- **Where the sign goes.** ADA 703.4 sets the height and place: the bottom row
  of braille at least 1220 mm (48 in) above the floor, the baseline of the top
  line of letters at most 1525 mm (60 in), and rules about which side of the
  door and the clear floor space in front of the sign.
- **Where the plates sit on the wall.** The plates are meant to touch, side
  rails meeting. ADA 703.3.2 asks 9.5 mm (3/8 in) between the braille and the
  raised letters; touching plates give 43.473 mm on the default sign and
  17.505 mm on a six-line sign, measured in the files.
- **Contrast and glare.** ADA 703.5.1 asks light letters on a dark background
  or dark on light, with a non-glare finish. A print in one color has no
  contrast; paint the letters or change filament.
- **Checked braille.** The samples come from liblouis and your own braille
  from whatever translator you use; neither is checked by a person.
- **Other fonts.** The letters are always Liberation Sans, whose proportions
  are measured above.

> **ADA note.** The defaults follow the published §703 figures, but this tool
> does **not** guarantee compliance. Real signage has requirements this
> generator does not model — mounting height and location, contrast, glare,
> character width ratios, and the 9.5 mm (3/8 in) minimum braille offset below
> the raised text. Verify against the standard before installing.

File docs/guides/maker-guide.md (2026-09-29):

# Maker Guide

This guide takes you from the words on a door to a tactile sign on the wall:
raised capital letters on one plate, the same words in braille on a second
plate below it. You choose how to make the files, prepare the wording and its
braille, fill in four Customizer steps, print each plate, mount the two plates
touching, and check the result by touch. The [quick start](quick-start.md) is
the same path on one page, and the [full guide](full-guide.md) explains every
dial.

1. [Choose a way](#1-choose-a-way)
2. [Prepare the wording](#2-prepare-the-wording)
3. [Customize](#3-customize)
4. [Print](#4-print)
5. [Mount](#5-mount)
6. [Check it](#6-check-it)

## 1. Choose a way

There are four ways to get the two STL files, the files your printer's slicer
reads:

- **Desktop OpenSCAD.** Free software for Windows, macOS and Linux, 2021.01 or
  newer, from [the OpenSCAD downloads page](https://openscad.org/downloads.html).
  You get every dial, and the preview shows problems as red words beside the
  sign. The quick start's [Way 1](quick-start.md#way-1-desktop-openscad) walks
  through each click.
- **In your browser with the Forge.** The
  [OpenSCAD Assistive Forge](https://openscad-assistive-forge.pages.dev/) runs
  the generator in a panel built for screen readers and keyboards, and
  translates your wording into braille for you with liblouis, an open-source
  braille translator. [Open this sign in the
  Forge](https://openscad-assistive-forge.pages.dev/?example=braille-sign). The
  Forge updates its own copy of the generator separately, so its dial names
  and defaults can differ from this guide's.
- **MakerWorld.** Once the sign is listed there, MakerWorld's Parametric Model
  Maker runs the same file in your browser. It cannot translate braille and
  shows no warnings; [the MakerWorld quick
  start](../MAKERWORLD_QUICK_START.md) covers it.
- **A ready-made sample.** Restroom, Exit, Stairs and Room 101 are ready to
  print in [the stl folder](../../stl/README.md). There is nothing to
  customize: go straight to [4. Print](#4-print).

## 2. Prepare the wording

Each line you type becomes one line of raised capital letters, and each line
gets its own line of braille below. A sign can have up to six lines.

1. Write the sign's wording, one line of the sign per line of text.
2. Translate each line into Unicode braille, Grade 2, in lowercase except for
   names, single letters, initials and acronyms. The quick start's
   [Translating your wording](quick-start.md#translating-your-wording) has the
   steps; the Forge does this for you.
3. Keep each braille line beside its text line: braille line 1 goes with text
   line 1, and so on.

Unicode braille is the set of dot-pattern characters from U+2800 to U+28FF.
Grade 2, or contracted braille, shortens common words and letter groups, and
it is what ADA 703.3 asks for on signs.

**An automatic translator is not a certified transcriber.** For a sign in a
public building, have a transcriber certified in Unified English Braille (UEB)
check the braille before you print.

## 3. Customize

Open `Braille_Sign_STL_Generator.scad` and show the Customizer. The first four
tabs are the steps; fill them in from top to bottom.

1. In **Step 1 - Pick a sample sign or type your own**, set `sample_sign` to a
   sample, or leave it on `Type my own` and type your lines into
   `text_line_1` to `text_line_6`.
2. In **Step 2 - Braille, pasted from a translator**, paste each braille line
   into the matching `braille_line_1` to `braille_line_6`. A sample needs none.
3. In **Step 3 - What to export**, set `sign_part` to `Letter plate` for the
   first file. Leave `print_orientation` on `Angled`.
4. In **Step 4 - Size**, leave `auto_fit` on `Yes`. `sign_width_mm`,
   `letter_plate_height_mm` and `braille_plate_height_mm` are then minimums:
   raise one only to make a plate bigger than your wording needs.
5. Look at the preview. Red words beside the sign name a problem to fix first;
   the full guide's [Warnings and notes](full-guide.md#warnings-and-notes)
   explains each one.
6. Render the letter plate (F6 in desktop OpenSCAD).
7. Export it as an STL file. The quick start's
   [Way 1](quick-start.md#way-1-desktop-openscad) names the desktop menu for
   each OpenSCAD version.
8. Set `sign_part` to `Braille plate`.
9. Repeat steps 6 and 7 for the braille plate.

Every other dial sits in a tab whose name starts with "Advanced -". The full
guide's [Every dial](full-guide.md#every-dial) says what each one changes, its
range, and the ADA figure behind it.

## 4. Print

Print each plate as its own job, exactly as the file lays it out: do not
rotate it, and do not add slicer supports.

| Setting | Letter plate | Braille plate |
|---|---|---|
| On the bed | flat, letters up | leaning back on its fins |
| Layer height | 0.2 mm | 0.1 mm |
| Material | PLA or PETG | PLA or PETG |
| Supports | none | none |
| Brim | not needed | optional; one is modeled under each fin |
| Outer wall speed | normal | 30 to 40 mm/s or slower |

In words: print the letter plate flat with its letters up, at 0.2 mm layers.
Print the braille plate as the file stands it, leaning back on its fins, at
0.1 mm layers with the outer wall at 30 to 40 mm/s or slower. Use PLA or PETG
for both, with no slicer supports; the small brim under each fin is part of
the file. The braille plate gets the fine layers because a braille dot is at
most 0.9 mm (0.037 in) tall, so the layer height decides how smooth it feels,
and the slow outer wall because a thin leaning plate shakes at speed.

<!-- photo: shot list item 4 -->
<!-- photo: shot list item 3 -->

When the braille plate is off the bed:

1. Flex or snip the fins off the back of the braille plate.
2. Smooth the small nubs left where the fins joined, with a fingernail or fine
   sandpaper.

A print in one color has no contrast, and signs need light letters on a dark
background or dark on light. Paint the raised letters, or change filament at
the top of the plate: the quick start's [Contrast](quick-start.md#contrast)
section says how.

## 5. Mount

The plates have flat backs and no holes: they go up with adhesive strips or
double-sided tape. The letter plate carries the top and side rails of the
raised border, and the braille plate carries the bottom and side rails, so
mounted touching they make one frame. Where on the wall the sign goes, and on
which side of the door, is in the User Guide's
[Where it goes](user-guide.md#where-it-goes).

1. Clean the wall where the sign goes, and let it dry.
2. Hold the two plates against the wall together, letters above braille, with
   their side rails meeting.
3. Move them until the bottom row of braille is at least 1220 mm (48 in) above
   the floor and the baseline of the top line of letters, the line the letters
   stand on, is at most 1525 mm (60 in) above the floor.
4. Mark the wall along the top edge of the letter plate.
5. Stick adhesive strips or double-sided tape to the back of each plate.
6. Press the letter plate onto the wall with its top edge on the mark.
7. Press the braille plate onto the wall right below it, pushed up until the
   side rails meet.
8. Hold both plates firmly against the wall for as long as the tape's
   instructions say.

<!-- photo: shot list item 2 -->
<!-- photo: shot list item 1 -->

ADA 703.3.2 asks for at least 9.5 mm (3/8 in) between the braille and the
raised letters. With the plates touching, the generator's spacing already
gives more than that: about 43 mm on the default sign.

## 6. Check it

1. Run a fingertip across the braille: each dot should feel round and firm,
   with no cell missing.
2. Read the braille, or, if you do not read braille, compare each cell with
   the braille your translator gave, dot by dot.
3. Measure a dot with calipers that have a depth rod, if you have them: it
   stands about 0.7 mm above the plate.
4. Measure a flat-topped capital letter, such as E, H or T, with a ruler or
   calipers: at the default `letter_height_mm` it is 16 mm tall.
5. Run your hand around the frame: it should feel like one edge, with no step
   where the plates meet.

<!-- photo: shot list item 5 -->
<!-- photo: shot list item 6 -->

> **ADA note.** The defaults follow the published §703 figures, but this tool
> does **not** guarantee compliance. Real signage has requirements this
> generator does not model — mounting height and location, contrast, glare,
> character width ratios, and the 9.5 mm (3/8 in) minimum braille offset below
> the raised text. Verify against the standard before installing.

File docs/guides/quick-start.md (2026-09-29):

# Quick start

This page takes you from "I need a sign" to a finished sign on the wall: a
plate of raised letters with a braille plate below it. You do not need to know
3D modeling or code. Every setting is named here exactly as it appears in the
Customizer, OpenSCAD's panel of settings, so you can find it by name.

## What you are making

The generator makes a room sign in two parts. The **letter plate** carries the
words in raised capital letters, for reading by sight or by touch. The
**braille plate** carries the same words in braille. They are separate plates
because each prints best a different way: raised letters print cleanly lying
flat, and braille dots print smoothest on a plate that leans back at 75
degrees. When you mount them with the letters above the braille, the raised
borders of the two plates join into one frame around the sign.

<!-- photo: shot list item 2 -->

The picture below shows the default sign the way the printer makes it: the
letter plate lies flat with ROOM 101 in raised letters inside a raised border,
and the braille plate leans back on a row of thin support fins that you snap
off after printing. This view shows the back of the braille plate, so its dots
face away from you.

The default sign as it prints, seen from above and in front. The letter plate lies flat with ROOM 101 in raised capital letters inside a raised border. In front of it the braille plate leans back on a row of thin support fins; this view shows its back and fins, and its braille dots face away.

Seen from straight above, the plates sit the way they hang on the wall: the
letter plate on top, and the braille plate below it with its row of dots. The
raised letters are flat on top, so from this angle they barely show.

Both plates of the default sign seen from straight above. The letter plate is at the top; from this angle its raised ROOM 101 shows only as faint outlines. Below it the braille plate shows its raised border and one short row of braille dots across the middle.

## What you need

- A 3D printer with a bed at least 170 mm wide for the default sign. Longer
  wording makes wider plates.
- PLA or PETG filament.
- The wording for your sign.
- Its braille: a braille translator, or the OpenSCAD Assistive Forge, which
  translates for you (Way 2).
- Adhesive strips or double-sided tape, and a tape measure, for mounting.

If you want one of the sample signs as it is (Restroom, Exit, Stairs or Room
101), both plates are ready to print in [the stl folder](../../stl/README.md):
skip to [Printing](#printing).

## Way 1: desktop OpenSCAD

OpenSCAD is a free program that turns the generator file into STL files you
can print. The two plates print best with different settings, so you export
them one at a time.

1. Download and install OpenSCAD 2021.01 or newer from [the OpenSCAD downloads
   page](https://openscad.org/downloads.html). A development snapshot renders
   this sign much faster: in seconds, where 2021.01 takes about a minute.
2. Download [`Braille_Sign_STL_Generator.scad`](../../Braille_Sign_STL_Generator.scad).
3. Open it in OpenSCAD with File > Open.
4. Show the Customizer panel: in the Window menu, tick Customizer. In OpenSCAD
   2021.01, untick Window > Hide Customizer instead.
5. In **Step 1 - Pick a sample sign or type your own**, set `sample_sign` to
   `Restroom`, `Exit`, `Stairs` or `Room 101`, or leave it on `Type my own`.
   A sample brings its own wording and braille, so go on to step 8.
6. Type your wording into `text_line_1`, one line of the sign per setting,
   with `text_line_2` to `text_line_6` for more lines.
7. In **Step 2 - Braille, pasted from a translator**, paste the braille for
   each line into the matching `braille_line_1` to `braille_line_6`: see
   [Translating your wording](#translating-your-wording).
8. Look at the preview, the picture that updates as you change a setting. Red
   words beside the sign mean something needs fixing: see [If something looks
   wrong](#if-something-looks-wrong).
9. In **Step 3 - What to export**, set `sign_part` to `Letter plate`.
10. Press F6 to render the plate, which builds its final shape.
11. Choose File > Export > Export as STL and save the file. Newer versions
    offer Export as STL (binary) and Export as STL (ascii); either works.
12. Set `sign_part` to `Braille plate`.
13. Press F6 again.
14. Export and save the braille plate the same way.

You can leave **Step 4 - Size** and the Advanced tabs alone: with `auto_fit`
on `Yes`, the plates grow to fit your wording.

<!-- photo: shot list item 7 -->

When you pick `Restroom` in step 5, the preview shows the letter plate reading
RESTROOM, and orange words beyond it remind you that a sample is in use.

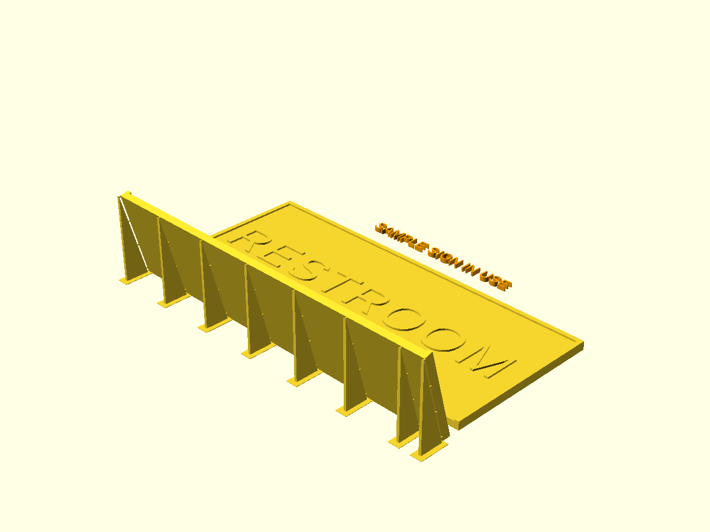
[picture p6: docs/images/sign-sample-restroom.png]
The Restroom sample in the preview. The letter plate reads RESTROOM in raised capital letters, the braille plate leans on its fins in front, and the orange words SAMPLE SIGN IN USE lie flat beyond the far edge of the letter plate.


## Way 2: in your browser with the Forge

The [OpenSCAD Assistive Forge](https://openscad-assistive-forge.pages.dev/)
runs this generator in your web browser, in a panel built for screen readers
and keyboards. It translates your wording into braille for you with liblouis,
an open-source braille translator, so you type plain words and can skip
[Translating your wording](#translating-your-wording). Open this sign in the
Forge:

<https://openscad-assistive-forge.pages.dev/?example=braille-sign>

The Forge keeps its own copy of the generator and updates it separately, so
its settings can have older names and defaults than the ones on this page.

## Way 3: MakerWorld

MakerWorld's Parametric Model Maker can run this file in your browser once the
sign is listed there. It cannot translate braille and shows no warnings, so you
paste braille from a translator and check the sizes yourself. [The MakerWorld
quick start](../MAKERWORLD_QUICK_START.md) walks you through it.

## Translating your wording

Skip this section if you picked a sample sign or use the Forge.

The braille lines take **Unicode braille**: characters that look like patterns
of dots, from the Unicode range U+2800 to U+28FF. ASCII braille, which looks
like ordinary letters and punctuation, does not work. Signs use contracted
braille (Grade 2, where common words and letter groups are shortened), as ADA
703.3 asks.

The steps below use [the Branah braille
translator](https://www.branah.com/braille-translator). Its own page says its
Grade 2 is still a work in progress and may shorten a word where it should
not, so check what it gives you, or use the Forge (Way 2), which translates
with liblouis.

1. Open the Branah braille translator.
2. Choose Grade 2 Braille.
3. Choose Unicode Braille.
4. Type one line of your wording in lowercase. Keep a capital only at the
   start of a sentence and for names, single letters, initials and acronyms:
   those are the only places ADA 703.3.1 allows the braille capital sign.
5. Copy the braille.
6. Paste it into the matching braille line: `braille_line_1` for line 1,
   `braille_line_2` for line 2, and so on.
7. Repeat steps 4 to 6 for each line.

**An automatic translator is not a certified transcriber.** For a sign in a
public building, have a transcriber certified in Unified English Braille (UEB)
check the braille before you print.

## Printing

Open each STL in your slicer, the program that prepares a file for your
printer. Print each plate as its own job, exactly as the generator lays it
out: do not rotate it, and do not add supports.

| Setting | Letter plate | Braille plate |
|---|---|---|
| On the bed | flat, letters up | leaning back on its fins |
| Layer height | 0.2 mm | 0.1 mm |
| Material | PLA or PETG | PLA or PETG |
| Supports | none | none |
| Brim | not needed | optional; one is modeled under each fin |
| Outer wall speed | normal | 30 to 40 mm/s or slower |

<!-- photo: shot list item 4 -->
<!-- photo: shot list item 3 -->

The braille plate gets the fine layers because a braille dot is at most 0.9 mm
(0.037 in) tall, so the layer height decides how smooth each dot feels. It gets the slow
outer wall because a thin plate leaning at 75 degrees wobbles at speed.

## After printing

1. Flex or snip the fins off the back of the braille plate.
2. Smooth the small nubs left where the fins joined the plate, with a
   fingernail or fine sandpaper.
3. Run a fingertip across the braille: each dot should feel round and firm,
   with no strings or blobs.
4. Measure a flat-topped capital letter, such as E, H, R or T, with a ruler or
   calipers: at the default `letter_height_mm` it is 16 mm tall. Round letters
   such as O and S stand about 0.5 mm taller.

<!-- photo: shot list item 5 -->
<!-- photo: shot list item 6 -->

## Mounting

The two plates touch on the wall. The letter plate carries the top and side
rails of the raised border, and the braille plate carries the bottom and side
rails, so when the plates meet, the rails run as one frame around the sign.

1. Lay the letter plate above the braille plate, both face up.
2. Push the plates together until their side rails meet in one straight line.
3. Stick adhesive strips or double-sided tape to the back of each plate.
4. Pick the height on the wall: the bottom row of braille at least 1220 mm
   (48 in) above the floor, and the baseline of the top line of letters (the
   line the letters stand on) at most 1525 mm (60 in) above the floor.
5. Press the letter plate onto the wall.
6. Press the braille plate onto the wall right below it, with the side rails
   meeting.

<!-- photo: shot list item 1 -->

ADA 703.3.2 asks for at least 9.5 mm (3/8 in) between the braille and the
raised letters. With the plates touching, the generator's spacing already
gives more than that: about 43 mm on the default sign.

> **ADA note.** The defaults follow the published §703 figures, but this tool
> does **not** guarantee compliance. Real signage has requirements this
> generator does not model — mounting height and location, contrast, glare,
> character width ratios, and the 9.5 mm (3/8 in) minimum braille offset below
> the raised text. Verify against the standard before installing.

## Contrast

The ADA Standards ask for raised letters that contrast with their background,
light on dark or dark on light, with a matte finish that does not glare. The
braille does not need to contrast. A print in one color has no contrast, so use
one of these:

- If your slicer can pause for a filament change, add one at the first layer
  above 3 mm, the top of the plate at the default `plate_thickness_mm`, so the
  raised letters and border print in the second color.
- Otherwise, paint the raised letters in a matte color that contrasts with the
  plate.

## If something looks wrong

When the generator finds a problem, it writes it in red beside the sign in the
preview. The words disappear when you render with F6, and they never reach the
STL. The console under the preview prints the same problem with its numbers.

- `NOT BRAILLE IN LINE 1` (or another line number): that braille line holds
  typed letters or ASCII braille. Paste Unicode braille from a translator.
- `TEXT TOO WIDE`: set `auto_fit` to `Yes`, raise `sign_width_mm`, or shorten
  the line.
- `TEXT TOO TALL`: set `auto_fit` to `Yes`, raise `letter_plate_height_mm`, or
  remove a line.
- `BRAILLE TOO WIDE`: set `auto_fit` to `Yes`, raise `sign_width_mm`, or
  shorten the line.
- `BRAILLE TOO TALL`: set `auto_fit` to `Yes`, raise `braille_plate_height_mm`,
  or remove a line.
- `BRAILLE TOO CLOSE TO BORDER`: the braille fits but sits closer than
  `braille_clearance_mm` to the border or the plate edge. Set `auto_fit` to
  `Yes`, raise `braille_plate_height_mm` or `sign_width_mm`, or shorten the
  braille.
- `LETTERS UNDER 16 MM`: `letter_height_mm` is under 16 mm (5/8 in), and ADA
  703.2.5 asks 16 mm or more. Raise it to 16 or more.
- `SAMPLE SIGN IN USE`, in orange: a sample is picked in `sample_sign`, so the
  text and braille lines are ignored. Set `sample_sign` to `Type my own` to use
  your own wording.

With typed letters in `braille_line_1`, the preview shows the red words NOT
BRAILLE IN LINE 1 beyond the far edge of the letter plate.

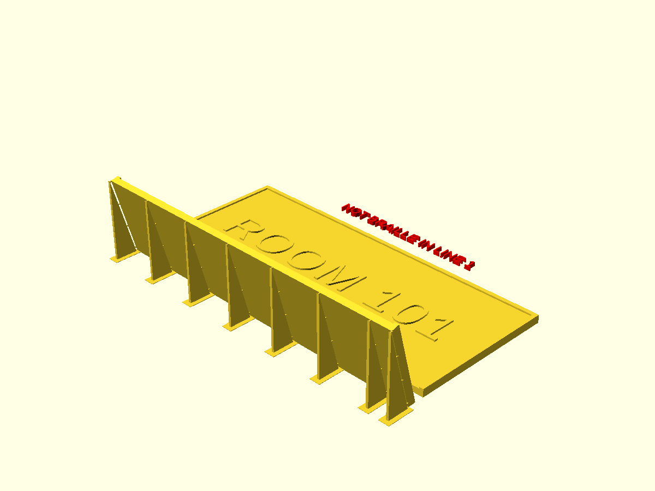
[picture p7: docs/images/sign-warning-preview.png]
The default sign in the preview with the red words NOT BRAILLE IN LINE 1 lying flat just beyond the far edge of the letter plate. The letter plate shows ROOM 101 in raised letters, and the braille plate leans on its fins in front.


MakerWorld shows none of these words and has no console: [the MakerWorld quick
start](../MAKERWORLD_QUICK_START.md#7-troubleshooting) lists what each problem
looks like there. The [full guide](full-guide.md) explains every warning and
note, when each one appears, and how to fix it.

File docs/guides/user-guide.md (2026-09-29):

# User Guide

This guide is for the people who put up, read and look after a sign made with
the Braille Sign STL Generator. How to make one is in the
[Maker Guide](maker-guide.md).

## Who the sign is for

The sign is for anyone who reads by touch or by sight. The raised capital
letters and the braille below them carry the same words, so a braille reader,
a reader who finds the letters with their fingers, and a sighted reader all get
the same wording from one sign.

## Where it goes

ADA 703.4 sets where a sign with tactile characters goes. In plain words:

- **Height.** The bottom row of braille at least 1220 mm (48 in) above the
  floor, and the baseline of the top line of letters, the line the letters
  stand on, at most 1525 mm (60 in) above the floor.
- **At a single door.** Beside the door, on the latch side: the side with the
  handle, away from the hinges. If there is no wall there, on the nearest wall.
  A door that closes by itself and has nothing to hold it open may carry the
  sign on its push side.
- **At double doors.** Where only one door opens, on the door that stays shut.
  Where both open, to the right of the right-hand door.
- **Room to stand.** A clear space of at least 455 by 455 mm (18 by 18 in) on
  the floor, centered on the letters and braille, outside the path any door
  sweeps between shut and 45 degrees open, so a reader is not hit by the door.

<!-- photo: shot list item 1 -->

## Reading it

The letters are on top and the braille directly below them. A raised frame
runs around the whole sign: the letter plate carries its top and sides, the
braille plate its bottom and sides, and together they mark where the sign
starts and ends under a hand.

Each line of letters has its own line of braille, in the same order. On a sign
made as the Maker Guide describes, the braille is Grade 2, or contracted
braille, where common words and letter groups are shortened, as ADA 703.3
asks, and it uses a capital sign only before a name, a single letter, initials
or an acronym, as ADA 703.3.1 asks.

<!-- photo: shot list item 5 -->

## Care

- Wipe the sign with a damp cloth, with a little mild soap if it is dirty, and
  dry it.
- Use no solvents: they attack PLA and PETG, the plastics the sign is printed
  in.
- Keep the sign away from heaters and strong sun on a hot wall; the plastic
  softens when hot.
- Now and then, run a fingertip across the braille. A plate whose dots have
  worn down or broken off can no longer be read reliably: print a new one from
  the same settings and replace it.
- If a plate comes loose, clean both surfaces and stick it back with fresh
  tape, the side rails lined up with the other plate.

## Limits

- **It is not a guarantee.** The generator follows the published figures, but
  a sign's compliance depends on things it cannot see, as the note below says.
- **The braille is only as good as its translation.**
  An automatic translator is not a certified transcriber.
  For a sign in a public building, have a transcriber certified in Unified
  English Braille (UEB) check the braille.
- **Contrast is the maker's job.** ADA 703.5.1 asks light letters on a dark
  background or dark on light, with a non-glare finish. A print in one color
  has no contrast until the letters are painted or printed in a second color.

> **ADA note.** The defaults follow the published §703 figures, but this tool
> does **not** guarantee compliance. Real signage has requirements this
> generator does not model — mounting height and location, contrast, glare,
> character width ratios, and the 9.5 mm (3/8 in) minimum braille offset below
> the raised text. Verify against the standard before installing.

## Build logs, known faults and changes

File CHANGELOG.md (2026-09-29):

# Changelog

All notable changes to this project are documented in this file.

The format is based on [Keep a Changelog](https://keepachangelog.com/en/1.1.0/),
and this project adheres to [Semantic Versioning](https://semver.org/spec/v2.0.0.html).

## [Unreleased]

### Added

- **A sample-sign dial.** `sample_sign`, the first dial of Step 1, picks
  Restroom, Exit, Stairs or Room 101, each with its own wording and its Unified
  English Braille Grade 2 braille, lowercase with no capital sign, generated by
  liblouis with `scripts/generate_sample_braille.mjs` into
  `scripts/sample_signs.json`. The default stays `Type my own`. A picked sample
  prints a console note and shows SAMPLE SIGN IN USE in orange in the preview.
- **`braille_clearance_mm`** (default and minimum 9.5 mm, the ADA 703.3.2
  figure): auto-fit keeps the braille that far inside the border rails. With
  `auto_fit` off, a new warning, BRAILLE TOO CLOSE TO BORDER, reports braille
  that fits the plate but lacks the space.
- **Warnings in the preview only.** `show_warnings` (default `Yes`) draws each
  problem as red text beside the sign in the desktop preview, with OpenSCAD's
  background modifier, so it never reaches a render or an STL: NOT BRAILLE IN
  LINE n, TEXT TOO WIDE, TEXT TOO TALL, BRAILLE TOO WIDE, BRAILLE TOO TALL,
  BRAILLE TOO CLOSE TO BORDER, LETTERS UNDER 16 MM, and SAMPLE SIGN IN USE in
  orange.
- **Console notes** for `letter_height_mm` under 16 mm, `letter_raise_mm` under
  0.8 mm and `letter_line_spacing_pct` outside 135 to 170, each naming its ADA
  703.2 figure, and a `Text width estimate: {N} mm` line.
- **Checks that stop the render** when a braille dial is set outside ADA Table
  703.3.1, or `braille_clearance_mm` under 9.5 mm, from a preset or the command
  line, each with a message naming the dial and the figure.
- **A ready-to-print library** in `stl/`: both plates of the four samples as
  binary STLs, with `stl/README.md`, built by `scripts/build_release_stls.py`.
- **Documentation:** `docs/guides/quick-start.md`, `docs/guides/full-guide.md`,
  `docs/guides/maker-guide.md`, `docs/guides/user-guide.md`,
  `docs/guides/bom.md` and `docs/guides/design-rationale.md`, with preview
  pictures in `docs/images/` rendered by `scripts/render_doc_images.py`, and
  `okh.yml`, the Open Know-How manifest.
- **A documentation gate**, `scripts/check_docs.py`, run by
  `tests/test_docs_gate.py`.
- **Tests:** `tests/test_sample_signs.py`, `tests/test_ada_figures.py`,
  `tests/test_release_stls.py`, `tests/test_full_guide_covers_every_dial.py` and
  `tests/test_docs_gate.py`; new guards in `tests/test_source_guards.py` (the
  tab layout, dropdown labels, the braille sliders) and
  `tests/test_render_smoke.py` (warnings never exported).
- **Scripts:** `scripts/measure_glyph_advances.py`, which measures every
  character's width into `scripts/glyph_advances.json`, and the scripts named
  above, all listed in `scripts/README.md`.

### Changed

- **The Customizer reads top to bottom:** four Steps (`Step 1 - Pick a sample
  sign or type your own`, `Step 2 - Braille, pasted from a translator`,
  `Step 3 - What to export`, `Step 4 - Size`) and six Advanced tabs
  (`Advanced - Plates and border`, `Advanced - Raised letters, ADA 703.2`,
  `Advanced - Braille spacing, ADA 703.3`, `Advanced - Braille dot shape`,
  `Advanced - Braille plate lean and support fins`,
  `Advanced - Warnings and rendering`), with one plain sentence under each
  dial. The file's header walks through the four Steps.
- **Renamed dials.** A saved preset or a `-D` script must use the new names:
  OpenSCAD ignores an old name without a message and leaves that dial at its
  default.

  | Old name | New name |
  |---|---|
  | `sign_text_1` to `sign_text_6` | `text_line_1` to `text_line_6` |
  | `Line_1` to `Line_6` | `braille_line_1` to `braille_line_6` |
  | `char_height_mm` | `letter_height_mm` |
  | `line_spacing_pct` | `letter_line_spacing_pct` |
  | `letter_spacing` | `letter_spacing_factor` |
  | `cell_spacing` | `braille_cell_spacing_mm` |
  | `line_spacing` | `braille_line_spacing_mm` |
  | `dot_spacing` | `braille_dot_spacing_mm` |
  | `part_gap_mm` | `plate_gap_mm` |
  | `cone_dot_flat_hat` | `cone_dot_top_diameter` |
  | `cone_segments` | `dot_segments` |

- **Toggles say `Yes` or `No`:** `add_border` (was `yes`/`no`) and
  `support_fins` (was `On`/`Off`). An old preset's `yes` or `On` now counts as
  `No`, so it would lose its border or its fins.
- **`letter_height_mm` is the printed height of the capital I**, the letter ADA
  703.2.5 measures: the file passes the dial divided by 0.9555, Liberation
  Sans's cap ratio, to `text()`. To keep an old preset's print size, multiply
  its `char_height_mm` by 0.9555.
- **The width estimate uses a per-character table**, `GLYPH_METRICS`, measured
  from Liberation Sans, and gives the width a centered line needs.
- **The ten braille sliders** (the dot diameters, heights and cone top, and the
  three spacings) span ADA Table 703.3.1 and no further. `dot_shape` says Cone
  is not the ADA dot shape.
- **The default cell pitch is 6.5 mm** (was 7.0), in the file and both presets.
- **The console's summary line** prints millimeters to one decimal through
  `mm1()`.
- **The README** follows the Open Assistive Technology template's order.
- **CI's quick job** runs every test not marked `requires_openscad`, instead of
  two named files.

### Fixed

- **The capital I printed 15.29 mm tall at the 16 mm default**, under the ADA
  703.2.5 figure every document claimed; it now prints 16.000 mm.
- **Braille sat 4 mm from the border rail on multi-line signs**, where ADA
  703.3.2 asks 9.5 mm; it now sits 9.5 mm away.
- **The width estimate was off by up to 27 %:** eight W's printed 182.3 mm wide
  on a 160 mm plate, hanging past both ends with no warning. The estimate is now
  within 2 % and never narrower than the letters, so auto-fit widens the plate
  instead.
- **The braille dot sliders reached far outside ADA 703.3.1**, and nothing
  stopped a value there.
- **A braille line holding typed letters printed a plate with dots missing and
  said so only in the console;** the preview now shows NOT BRAILLE IN LINE n.
- **The summary line printed raw floats** such as 200.978.
- **The letter-height note and the documents said 15.9 mm;** ADA 703.2.5 prints
  "5/8 inch (16 mm)", and the note, the warning and the documents now say 16.
- **The README's parameter table named tabs that never existed, and its
  troubleshooting quoted warnings the file never prints;** both are gone, and
  the full guide lists every dial and message.
- **Three toggle vocabularies, an ADA comment attached to no dial, a
  three-line description of which the Customizer showed one line, and
  confusable names**, fixed by the reorder and the renames above.

## [1.0.1] - 2026-08-01

### Changed

- **Overflow warnings now report measured size against available space**, in the
  counted style the sibling cylinder generator uses for `TEXT TOO LONG: n/capacity`.
  The four warnings previously said only that something was too tall or too wide,
  which told you a problem existed but not how big it was or how much to change —
  so fixing it by hand meant guessing, rendering, and guessing again. They now
  read e.g. `WARNING: BRAILLE TOO WIDE: 242.1/156 mm (longest line is 35 cells).
  Turn on auto_fit, raise sign_width_mm to at least 246.1, or shorten the line.`
  The thresholds themselves are unchanged, so nothing warns that did not warn
  before; only the message is more useful. Geometry is untouched.
- Added a `mm1()` helper so millimetre figures print to one decimal instead of
  as raw floats like `47.32499999999999`, and hoisted the repeated
  `border_on ? border_width_mm : 0` inset into named `_inner_w` /
  `_letter_inner_h` / `_braille_inner_h` values shared by the checks and their
  messages — the warning can no longer describe a different limit than the one
  that triggered it.

## [1.0.0] - 2026-07-27

First release as a standalone repository.

**Commit history lives in
[braille-wedge-card-openscad](https://github.com/BrennenJohnston/braille-wedge-card-openscad),**
where this generator was introduced in v1.1.0 (2026-07-12) alongside the wedge
card and the charm. That repo now holds the wedge card only. This repository
starts with fresh history; nothing about the generator itself changed in the
move.

### Added

- **`Braille_Sign_STL_Generator.scad`** — two-part ADA-style tactile sign:
  raised-letter plate (Liberation Sans, uppercase, 16 mm, 0.8 mm raise) plus a
  braille plate (flat or 75° angled with break-away fins), a split raised border
  that joins into one continuous frame when the plates are mounted together,
  auto-fit sizing, and `sign_part` = Both / Letter plate / Braille plate.
- **`Braille_Sign_STL_Generator.json`** presets: Default Sign (both plates) and
  Braille Plate Only (flat).
- **Test suite and CI.** Customizer dropdown hygiene and preset/parameter
  consistency tests, source-invariant guards (single-file MakerWorld
  requirement, `sign_part` export options, matching letter/braille row pairs,
  pinned font), and OpenSCAD render smoke tests asserting watertight exports
  with the expected body count for the two-plate sign, the angled braille plate,
  and the letter plate. GitHub Actions runs lint + quick tests + render smoke on
  Ubuntu.
- **README** covering the desktop workflow, print guidance, troubleshooting,
  MakerWorld upload steps, and the ADA disclaimer.
- **PolyForm Noncommercial 1.0.0 LICENSE.**

### Changed (vs. the wedge card repo)

- The test suite is scoped to this one generator: `conftest.py` declares a single
  `.scad`, and the card-only guards (20 `Line_N` parameters, `_all_lines`
  wiring, preview-only warnings, the `text()`-outside-`warning_slot` guard, and
  the de-embossing mission guard) are gone. Sign-specific structural guards
  replace them.
- The `.scad` header records that this generator now lives in its own repo.

[Unreleased]: https://github.com/BrennenJohnston/braille-sign-openscad/compare/v1.0.1...HEAD
[1.0.1]: https://github.com/BrennenJohnston/braille-sign-openscad/releases/tag/v1.0.1
[1.0.0]: https://github.com/BrennenJohnston/braille-sign-openscad/releases/tag/v1.0.0

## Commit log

2026-07-27 feat: braille sign generator as a standalone repo (v1.0.0)
    Split out of braille-wedge-card-openscad, which held three unrelated
    generators sharing nothing but a test harness and a README. Each one has
    its own audience, its own MakerWorld listing, and its own version number,
    so a single repo meant every release note and every CI run talked about
    two tools the reader did not care about.
    Fresh history; the sign's development history stays in
    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
    [Braille_Sign_STL_Generator.scad]
2026-07-27 ci: pin ruff and declare the rule set explicitly
    CI installed ruff unpinned, so the lint verdict depended on which version
    pip happened to resolve that day. Ruff 0.16 turned UP/PIE/BLE/PLW/RUF on by
    default and failed the lint job on an unchanged tree — 29 findings in code
    that had passed hours earlier.
    Adds ruff.toml selecting E + F + I with E501 ignored, which is what the
    suite was actually written against, and pins ruff==0.16.0 in the workflow
    so the rules and the version both live in the repo. The --ignore E501 flag
    moves out of the workflow into the config.
    known-first-party covers conftest and openscad_runner: pytest puts tests/
    on sys.path so they are imported by bare name, and wi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
2026-08-02 feat(warnings): report measured size against available space (v1.0.1)
    The four overflow warnings said only that something was too tall or too
    wide. That tells you a problem exists but not how big it is or how much
    to change, so fixing it by hand meant guessing, rendering, and guessing
    again. They now follow the counted style the sibling cylinder generator
    uses for TEXT TOO LONG: n/capacity, for example
    WARNING: BRAILLE TOO WIDE: 242.1/156 mm (longest line is 35 cells).
    Turn on auto_fit, raise sign_width_mm to at least 246.1, or shorten
    the line.
    The thresholds are unchanged, so nothing warns that did not warn
    before; only the message is more useful. Geometry is untouched.
    Adds an mm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
    [Braille_Sign_STL_Generator.scad]
2026-08-02 Bump checkout, setup-python, and upload-artifact to v7
    The v4/v5 pins run on the deprecated Node 20 runtime. This is catching up with
    the rest of the family rather than diverging: braille-cylinder-stl-generator
    already runs @v7 across all three actions and its CI is green.
2026-09-29 feat(samples): add liblouis sample-sign data and its lock test
    The sample_sign dial (next phase) takes each sample's wording and UEB
    Grade 2 braille from scripts/sample_signs.json. The new generator writes
    that file with the Assistive Forge's liblouis and table chain, so no
    braille in the repository is typed by hand, and test_sample_signs.py
    locks the file's shape. scripts/README.md starts the list of scripts.
    Claude-Session: https://claude.ai/code/session_01UZX4SGSq3RnNa9pcUoFmnM
2026-09-29 feat(customizer): four Steps and Advanced tabs, renamed dials, sample signs
    The Customizer now reads top to bottom: Step 1 to Step 4 for a beginner
    (a sample_sign dial with the four liblouis samples, the text and braille
    lines, what to export, size), then six Advanced tabs. The confusing dials
    take the plan's new names (text_line_N, braille_line_N, letter_height_mm,
    letter_line_spacing_pct, letter_spacing_factor, braille_cell_spacing_mm,
    braille_line_spacing_mm, braille_dot_spacing_mm, plate_gap_mm,
    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
    [Braille_Sign_STL_Generator.scad]
2026-09-29 fix(letters): letter_height_mm is the printed capital I; width estimate within 2 %
    ADA 703.2.5 measures raised characters on the uppercase I. The dial fed
    text() directly, and Liberation Sans draws its I at 0.9555 of the text
    size, so 16 printed a 15.29 mm I. text() now gets the dial divided by
    that ratio: 16 prints 16.000 mm (12 and 50 print 12.000 and 49.999).
    The auto-fit width estimate assumed 0.94 x size per character. That read
    "ROOM 101" 11 % wide and eight W's 27 % narrow, which let wide wording
    overhang the 160 mm plate with no warning. A per-character table of
    advance and ink edges, measured with textmetrics() by the new
    scripts/measure_glyph_advances.py, now gives the width a cen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
    [Braille_Sign_STL_Generator.scad]
2026-09-29 fix(braille): keep braille 9.5 mm from the border (ADA 703.3.2)
    Auto-fit padded the braille block 4 mm inside the border, so a six-line
    sign put its braille 4.0 mm from the bottom rail where ADA 703.3.2 asks
    9.5 mm. A new braille_clearance_mm dial (default and minimum 9.5 mm,
    asserted) now pads the braille plate; the letter plate keeps its 4 mm.
    The default sign does not change (its plate is at the 40 mm minimum);
    the six-line sign's braille plate grows from 68.6 to 79.6 mm and its
    braille sits 9.505 mm from the rail.
    With auto_fit off, a new BRAILLE TOO CLOSE TO BORDER warning reports
    braille that fits the plate but not with the clearance, for height and
    width. It allows a tolerance of 1e-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
    [Braille_Sign_STL_Generator.scad]
2026-09-29 fix(braille): hold the dot dials to ADA 703.3.1; cell pitch 6.5 mm
    The ten dials that shape or space the braille dots had sliders far
    outside ADA 703.3.1 (dot heights to 2 mm, dot spacing from 1 mm, cell
    spacing from 2 to 15 mm). Their sliders now span Table 703.3.1's printed
    metric ranges (dot base 1.5 to 1.6, dot height 0.6 to 0.9, dots 2.3 to
    2.5, cells 6.1 to 7.6, lines 10.0 to 10.2 mm), with dome, base-height
    and cone-top limits inside them. A -D value or a preset skips a slider
    and OpenSCAD does not check one, so an assert per dial, plus the total
    dot height, dome-within-base and cone-top checks, stops such a render
    with a message naming the dial and the figure.
    The default cell pitch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
    [Braille_Sign_STL_Generator.scad]
2026-09-29 feat(warnings): show problems as preview-only text beside the sign
    The warnings lived only in the desktop console, and a braille line that
    was not braille simply rendered a plate with no dots. A new
    show_warnings dial (default Yes) draws each problem as red text beside
    the sign in the preview: NOT BRAILLE IN LINE n, TEXT TOO WIDE, TEXT TOO
    TALL, BRAILLE TOO WIDE, BRAILLE TOO TALL, BRAILLE TOO CLOSE TO BORDER,
    LETTERS UNDER 16 MM, and SAMPLE SIGN IN USE in orange. The text uses
    the % background modifier, so it is never part of a render or an
    export: with warnings firing, the STL is identical with the dial Yes and
    No. Each condition is named once, and the console lines and the preview
    text bot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
    [Braille_Sign_STL_Generator.scad]
2026-09-29 feat(stl): ship ready-to-print STLs for the four sample signs
    stl/ now holds both plates of each built-in sample sign (Restroom, Exit,
    Stairs, Room 101): the letter plate, and the braille plate leaning on its
    break-away fins, rendered at the defaults. New
    scripts/build_release_stls.py renders them with the canonical OpenSCAD
    binary and --hardwarnings as binary STL, fails any file whose largest
    body is not watertight, and writes stl/README.md with each file's size
    and print settings. Tests keep the README and the folder in step, and
    check that a shipped plate matches a fresh render within 0.1 %.
    .gitignore now keeps stl/*.stl.
    Claude-Se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
    [exit-braille-plate.stl, exit-letter-plate.stl, restroom-braille-plate.stl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]
2026-09-29 docs(guides): add the quick start and the script that renders its pictures
    A beginner can now get from "I need a sign" to two plates on the wall
    with one page. docs/guides/quick-start.md covers desktop OpenSCAD, the
    Forge and MakerWorld, translating the wording to Unicode braille,
    printing each plate with its own settings, finishing, mounting and
    contrast, and lists every preview warning with its fix. Every setting is
    named exactly as the Customizer shows it, the ADA note is quoted
    verbatim, and the page says an automatic translator is not a certified
    transcriber.
    scripts/render_doc_images.py renders the page's four pictures into
    docs/images/ with the canonical OpenSCAD binary, so they can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
2026-09-29 docs(guides): add the full guide and a test that keeps it true to the file
    docs/guides/full-guide.md is the reference for makers who want more than
    the four Steps: how the two plates are built, every dial in Customizer
    order with its default, range and ADA figure, the four sample signs,
    every warning and note quoted in full with its fix, a table of the
    renamed dials for old presets and scripts, the command line, the tests,
    and what the generator leaves to you. It also warns that OpenSCAD
    ignores an old dial name without a message, and that an old preset's
    "yes" border and "On" fins now count as No.
    tests/test_full_guide_covers_every_dial.py fails if a dial loses its
    heading or its place, if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
2026-09-29 docs(guides): add the Maker Guide and the User Guide
    The two guides of the Open Assistive Technology document set. The Maker
    Guide walks a maker from the words on a door to a mounted sign: the four
    ways to get the files, the wording and its braille, the four Customizer
    steps, printing each plate, mounting the plates touching so the border
    joins into one frame, and checking the result by touch and with
    calipers. The User Guide is for the people who put the sign up, read it
    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
2026-09-29 docs(guides): add the bill of materials and the design rationale
    docs/guides/bom.md lists what a sign needs beyond the printer: filament,
    tape or adhesive strips, and paint or a second filament for contrast.
    Its filament table gives the grams per plate for each sample sign, from
    the solid volume of the shipped STLs at 1.27 g per cubic centimeter for
    PETG, as an upper bound.
    docs/guides/design-rationale.md explains each default in the shape the
    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
2026-09-29 docs(readme): rewrite the README in the OpenAT order and add okh.yml
    The README now follows the Open Assistive Technology template's order:
    overview, how to obtain the device (the Forge, desktop OpenSCAD, the
    ready-made STLs, MakerWorld), build instructions (the Maker Guide),
    how to use it (the User Guide), how to improve it (the full guide, the
    design rationale, the tests and scripts), files, license and
    attribution. Every dial name in it is today's, and the parts that had
    gone false are gone: the parameter table named tabs that never existed,
    and the troubleshooting table quoted warnings the file never prints.
    The full guide's warnings section replaces both.
    okh.yml is the Open Know-How m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
2026-09-29 docs(changelog): record the round's changes under Unreleased
    CHANGELOG.md gains an [Unreleased] section with what this round
    shipped: the sample-sign dial, the braille clearance, the preview-only
    warnings, the ADA checks, the STL library, the guides, the docs gate
    and the tests (Added); the Customizer reorder, the full table of renamed
    dials, the printed-height meaning of letter_height_mm, the width
    estimate, the 6.5 mm cell pitch and the README's new order (Changed);
    and the fixed defects, in plain words (Fixed). It also warns that an old
    preset's dial names are ignored and its old toggle values count as No.
    The missing [1.0.1] link line and an [Unreleased] compare line are
    added.
    tests/re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
2026-09-29 docs(makerworld): refresh the MakerWorld quick start and listing
    The MakerWorld pair still named the old dials, quoted 15.9 mm and the
    7.0 mm cell pitch, told users to set the 9.5 mm braille offset when
    mounting, and keyed its troubleshooting to console strings the file no
    longer prints.
    - MAKERWORLD_QUICK_START.md: A2's dial names; the four Steps with the
    sample dial first; 16.0 mm on the capital I, 6.5 mm with the corrected
    ISO sentence, and the 9.5 mm clearance dial; the plates-touch mount
    with the 703.4.1 heights; each problem's MakerWorld symptom beside its
    exact preview and console text; Branah's own Grade 2 caveat; the
    sample braille copied from scripts/sample_signs.json; t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
2026-09-29 docs(listings): add the Printables and Thingiverse listings
    Two upload-ready listing texts in docs/listings/, written to the shared
    documentation standard's listing template: the upload fields (the
    license CC BY-NC 4.0, the eight sample STLs, the .scad and its presets,
    the tags, the repository and the Forge link), a three-sentence summary,
    the description (the four samples file by file, the ADA note verbatim,
    the transcriber sentence, the Forge and desktop OpenSCAD paths with the
    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
2026-09-29 docs(listings): add the Makers Making Change submission packet
    Makers Making Change has no submission form, so the packet is written
    to be sent by email: what the device is and who it helps, where each
    OpenAT document lives in this repository, the files, the license in
    the LICENSE file's own terms (noncommercial, so not an open-source
    license, which the packet says plainly), the photos still to come, the
    readiness levels from okh.yml as the owner's claim, a checklist against
    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
